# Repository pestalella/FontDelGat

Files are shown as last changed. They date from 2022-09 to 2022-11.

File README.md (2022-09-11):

# FontDelGat
La Font del Gat: a 2 channel power supply. 
Features:
  * 2 output channels, up to 30V and 3A each
  * Possibility to link the 2 channels in series or in parallel
  * User input through buttons and a rotary encoder
  * LCD display to show the voltage and current limits and the actual outputs
  * Possibility to enable or disable the outputs independently

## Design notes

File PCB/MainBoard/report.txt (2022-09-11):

Info: Processing symbol 'U4:footprints:2SC5200NS1_E_S'.
Info: Processing symbol 'U7:Package_QFP:LQFP-64_10x10mm_P0.5mm'.
Info: Processing symbol 'C28:Capacitor_SMD:C_0603_1608Metric_Pad1.08x0.95mm_HandSolder'.
Info: Processing symbol 'C17:Capacitor_SMD:C_0805_2012Metric'.
Info: Processing symbol 'C18:Capacitor_SMD:C_0805_2012Metric'.
Info: Processing symbol 'U5:Package_SO:SOIC-8_3.9x4.9mm_P1.27mm'.
Info: Processing symbol 'C19:Capacitor_THT:CP_Radial_D16.0mm_P7.50mm'.
Info: Processing symbol 'C15:Capacitor_THT:CP_Radial_D8.0mm_P3.80mm'.
Info: Processing symbol 'C21:Capacitor_SMD:C_0603_1608Metric_Pad1.08x0.95mm_HandSolder'.
Info: Processing symbol 'U9:Package_TO_SOT_THT:TO-220-3_Vertical'.
Info: Processing symbol 'C30:Capacitor_SMD:C_0603_1608Metric_Pad1.08x0.95mm_HandSolder'.
Info: Processing symbol 'C23:Capacitor_SMD:C_0603_1608Metric_Pad1.08x0.95mm_HandSolder'.
Info: Processing symbol 'U3:Package_SO:SOIC-14_3.9x8.7mm_P1.27mm'.
Info: Processing symbol 'C24:Capacitor_SMD:C_0603_1608Metric_Pad1.08x0.95mm_HandSolder'.
Info: Processing symbol 'U2:Footprints:ltc2631cts8-hz12-trmpbf'.
Info: Processing symbol 'U1:Footprints:ltc2631cts8-hz12-trmpbf'.
Info: Processing symbol 'C8:Capacitor_SMD:C_1206_3216Metric_Pad1.42x1.75mm_HandSolder'.
Info: Processing symbol 'C1:Capacitor_SMD:C_0603_1608Metric_Pad1.08x0.95mm_HandSolder'.
Info: Processing symbol 'R2:Resistor_SMD:R_0805_2012Metric_Pad1.20x1.40mm_HandSolder'.
Info: Processing symbol 'R3:Resistor_SMD:R_0805_2012Metric_Pad1.20x1.40mm_HandSolder'.
Info: Processing symbol 'R27:Resistor_THT:R_Axial_DIN0207_L6.3mm_D2.5mm_P10.16mm_Horizontal'.
Info: Processing symbol 'Q10:Package_TO_SOT_THT:TO-92_HandSolder'.
Info: Processing symbol 'Q11:Package_TO_SOT_THT:TO-220-3_Vertical'.
Info: Processing symbol 'R34:Resistor_SMD:R_0805_2012Metric_Pad1.20x1.40mm_HandSolder'.
Info: Processing symbol 'Q12:Package_TO_SOT_THT:TO-220-3_Vertical'.
Info: Processing symbol 'R1:Resistor_SMD:R_0805_2012Metric_Pad1.20x1.40mm_HandSolder'.
Info: Processing symbol 'R28:Resistor_SMD:R_0805_2012Metric_Pad1.20x1.40mm_HandSolder'.
Info: Processing symbol 'Y1:Crystal:Crystal_HC49-U_Vertical'.
Info: Processing symbol 'C2:Capacitor_THT:CP_Radial_D8.0mm_P3.80mm'.
Info: Processing symbol 'C3:Capacitor_SMD:C_1206_3216Metric_Pad1.42x1.75mm_HandSolder'.
Info: Processing symbol 'R4:Resistor_SMD:R_0805_2012Metric_Pad1.20x1.40mm_HandSolder'.
Info: Processing symbol 'R26:Resistor_SMD:R_0805_2012Metric_Pad1.20x1.40mm_HandSolder'.
Info: Processing symbol 'R5:Resistor_SMD:R_0805_2012Metric_Pad1.20x1.40mm_HandSolder'.
Info: Processing symbol 'C20:Capacitor_THT:CP_Radial_D16.0mm_P7.50mm'.
Info: Processing symbol 'C16:Capacitor_SMD:C_0603_1608Metric_Pad1.08x0.95mm_HandSolder'.
Info: Processing symbol 'D1:Package_TO_SOT_SMD:SOT-23'.
Info: Processing symbol 'K3:Footprints:Relay_SPDT_Panasonic-ALQ105'.
Info: Processing symbol 'C27:Capacitor_SMD:C_0603_1608Metric_Pad1.08x0.95mm_HandSolder'.
Info: Processing symbol 'D3:Diode_SMD:D_SOD-123'.
Info: Processing symbol 'TP10:TestPoint:TestPoint_THTPad_D2.0mm_Drill1.0mm'.
Info: Processing symbol 'D2:Diode_SMD:D_SOD-123'.
Info: Processing symbol 'TP6:TestPoint:TestPoint_THTPad_D2.0mm_Drill1.0mm'.
Info: Processing symbol 'C26:Capacitor_SMD:C_0603_1608Metric_Pad1.08x0.95mm_HandSolder'.
Info: Processing symbol 'C29:Capacitor_SMD:C_0603_1608Metric_Pad1.08x0.95mm_HandSolder'.
Info: Processing symbol 'D4:Diode_SMD:D_SOD-123'.
Info: Processing symbol 'TP5:TestPoint:TestPoint_THTPad_D2.0mm_Drill1.0mm'.
Info: Processing symbol 'TP9:TestPoint:TestPoint_THTPad_D2.0mm_Drill1.0mm'.
Info: Processing symbol 'C31:Capacitor_SMD:C_1206_3216Metric_Pad1.33x1.80mm_HandSolder'.
Info: Processing symbol 'TP8:TestPoint:TestPoint_THTPad_D2.0mm_Drill1.0mm'.
Info: Processing symbol 'C32:Capacitor_SMD:C_0603_1608Metric_Pad1.08x0.95mm_HandSolder'.
Info: Processing symbol 'TP7:TestPoint:TestPoint_THTPad_D2.0mm_Drill1.0mm'.
Info: Processing symbol 'K1:Footprints:Relay_SPST_Panasonic_ALQ305'.
Info: Processing symbol 'C25:Capacitor_SMD:C_0603_1608Metric_Pad1.08x0.95mm_HandSolder'.
Info: Processing symbol 'C10:Capacitor_THT:CP_Radial_D8.0mm_P3.80mm'.
Info: Processing symbol 'C4:Capacitor_THT:CP_Radial_D8.0mm_P3.80mm'.
Info: Processing symbol 'C5:Capacitor_THT:CP_Radial_D5.0mm_P2.00mm'.
Info: Processing symbol 'C6:Capacitor_SMD:C_0603_1608Metric_Pad1.08x0.95mm_HandSolder'.
Info: Processing symbol 'C7:Capacitor_SMD:C_0603_1608Metric_Pad1.08x0.95mm_HandSolder'.
Info: Processing symbol 'Y2:Crystal:Crystal_C38-LF_D3.0mm_L8.0mm_Horizontal'.
Info: Processing symbol 'TP4:TestPoint:TestPoint_THTPad_D2.0mm_Drill1.0mm'.
Info: Processing symbol 'C9:Capacitor_SMD:C_1206_3216Metric_Pad1.42x1.75mm_HandSolder'.
Info: Processing symbol 'RV1:Footprints:Potentiometer_Panasonic_EVM1D_Vertical'.
Info: Processing symbol 'J3:Connector_Phoenix_MSTB:PhoenixContact_MSTBVA_2,5_3-G-5,08_1x03_P5.08mm_Vertical'.
Info: Processing symbol 'C11:Capacitor_THT:CP_Radial_D8.0mm_P3.80mm'.
Info: Processing symbol 'C12:Capacitor_THT:CP_Radial_D5.0mm_P2.00mm'.
Info: Processing symbol 'U10:Package_TO_SOT_THT:TO-220-3_Vertical'.
Info: Processing symbol 'C13:Capacitor_SMD:C_0603_1608Metric_Pad1.08x0.95mm_HandSolder'.
Info: Processing symbol 'C14:Capacitor_SMD:C_1206_3216Metric_Pad1.42x1.75mm_HandSolder'.
Info: Processing symbol 'U8:Package_TO_SOT_SMD:SOT-223-3_TabPin2'.
Info: Processing symbol 'D6:Package_TO_SOT_SMD:SOT-23'.
Info: Processing symbol 'TP2:TestPoint:TestPoint_THTPad_D2.0mm_Drill1.0mm'.
Info: Processing symbol 'D7:Package_TO_SOT_SMD:SOT-23'.
Info: Processing symbol 'Q1:Package_TO_SOT_THT:TO-220-3_Vertical'.
Info: Processing symbol 'Q2:Package_TO_SOT_SMD:SOT-23'.
Info: Processing symbol 'Q3:Package_TO_SOT_THT:TO-220-3_Vertical'.
Info: Processing symbol 'D11:LED_SMD:LED_0805_2012Metric_Castellated'.
Info: Processing symbol 'D5:Diode_SMD:D_SOD-123'.
Info: Processing symbol 'TP3:TestPoint:TestPoint_THTPad_D2.0mm_Drill1.0mm'.
Info: Processing symbol 'L1:Inductor_SMD:L_0805_2012Metric_Pad1.15x1.40mm_HandSolder'.
Info: Processing symbol 'R17:Resistor_SMD:R_0805_2012Metric_Pad1.20x1.40mm_HandSolder'.
Info: Processing symbol 'M1:Footprints:Fan_Orion_OD7020_vertical'.
Info: Processing symbol 'D8:Package_TO_SOT_SMD:SOT-23'.
Info: Processing symbol 'TP1:TestPoint:TestPoint_THTPad_D2.0mm_Drill1.0mm'.
Info: Processing symbol 'D9:Diode_THT:D_DO-35_SOD27_P10.16mm_Horizontal'.
Info: Processing symbol 'D10:LED_SMD:LED_0805_2012Metric_Castellated'.
Info: Processing symbol 'Q4:Package_TO_SOT_SMD:SOT-23'.
Info: Processing symbol 'R_sense2:Resistor_THT:R_Bare_Metal_Element_L21.3mm_W4.8mm_P20.30mm'.
Info: Processing symbol 'H1:MountingHole:MountingHole_4.3mm_M4_Pad_Via'.
Info: Processing symbol 'Q9:Package_TO_SOT_THT:TO-92_HandSolder'.
Info: Processing symbol 'J4:Connector_Molex:Molex_KK-254_AE-6410-04A_1x04_P2.54mm_Vertical'.
Info: Processing symbol 'R_sense1:Resistor_THT:R_Bare_Metal_Element_L21.3mm_W4.8mm_P20.30mm'.
Info: Processing symbol 'J5:Connector_PinHeader_1.27mm:PinHeader_2x07_P1.27mm_Vertical_SMD'.
Info: Processing symbol 'J6:Connector_Molex:Molex_KK-254_AE-6410-05A_1x05_P2.54mm_Vertical'.
Info: Processing symbol 'J7:Connector_Phoenix_MSTB:PhoenixContact_MSTBVA_2,5_4-G-5,08_1x04_P5.08mm_Vertical'.
Info: Processing symbol 'RV2:Footprints:Potentiometer_Panasonic_EVM1D_Vertical'.
Info: Processing symbol 'R30:Resistor_SMD:R_0805_2012Metric_Pad1.20x1.40mm_HandSolder'.
Info: Processing symbol 'Q8:Package_TO_SOT_SMD:SOT-23'.
Info: Processing symbol 'K2:Footprints:Relay_SPST_Panasonic_ALQ305'.
Info: Processing symbol 'J2:Connector_Phoenix_MSTB:PhoenixContact_MSTBVA_2,5_4-G-5,08_1x04_P5.08mm_Vertical'.
Info: Processing symbol 'K4:Footprints:Relay_SPDT_Panasonic-ALQ105'.
Info: Processing symbol 'R33:Resistor_SMD:R_0805_2012Metric_Pad1.20x1.40mm_HandSolder'.
Info: Processing symbol 'K5:Footprints:Relay_SPDT_Panasonic-ALQ105'.
Info: Processing symbol 'R32:Resistor_SMD:R_0805_2012Metric_Pad1.20x1.40mm_HandSolder'.
Info: Processing symbol 'R16:Resistor_SMD:R_0805_2012Metric_Pad1.20x1.40mm_HandSolder'.
Info: Processing symbol 'H2:MountingHole:MountingHole_4.3mm_M4_Pad_Via'.
Info: Processing symbol 'R12:Resistor_SMD:R_0805_2012Metric_Pad1.20x1.40mm_HandSolder'.
Info: Processing symbol 'R20:Resistor_SMD:R_0805_2012Metric_Pad1.20x1.40mm_HandSolder'.
Info: Processing symbol 'R13:Resistor_SMD:R_0805_2012Metric_Pad1.20x1.40mm_HandSolder'.
Info: Processing symbol 'R19:Resistor_SMD:R_0805_2012Metric_Pad1.20x1.40mm_HandSolder'.
Info: Processing symbol 'R14:Resistor_SMD:R_0805_2012Metric_Pad1.20x1.40mm_HandSolder'.
Info: Processing symbol 'R15:Resistor_SMD:R_0805_2012Metric_Pad1.20x1.40mm_HandSolder'.
Info: Processing symbol 'R18:Resistor_SMD:R_0805_2012Metric_Pad1.20x1.40mm_HandSolder'.
Info: Processing symbol 'R24:Resistor_SMD:R_0805_2012Metric_Pad1.20x1.40mm_HandSolder'.
Info: Processing symbol 'U6:footprints:2SC5200NS1_E_S'.
Info: Processing symbol 'R29:Resistor_SMD:R_0805_2012Metric_Pad1.20x1.40mm_HandSolder'.
Info: Processing symbol 'R31:Resistor_SMD:R_0805_2012Metric_Pad1.20x1.40mm_HandSolder'.
Info: Processing symbol 'Q5:Package_TO_SOT_SMD:SOT-23'.
Info: Processing symbol 'Q6:Package_TO_SOT_SMD:SOT-23'.
Info: Processing symbol 'Q7:Package_TO_SOT_SMD:SOT-23'.
Info: Processing symbol 'D12:Package_TO_SOT_SMD:SOT-23'.
Info: Processing symbol 'R21:Resistor_SMD:R_0805_2012Metric_Pad1.20x1.40mm_HandSolder'.
Info: Processing symbol 'C22:Capacitor_SMD:C_0603_1608Metric_Pad1.08x0.95mm_HandSolder'.
Info: Processing symbol 'R25:Resistor_SMD:R_0805_2012Metric_Pad1.20x1.40mm_HandSolder'.
Info: Processing symbol 'H3:MountingHole:MountingHole_4.3mm_M4_Pad_Via'.
Info: Processing symbol 'H4:MountingHole:MountingHole_4.3mm_M4_Pad_Via'.
Info: Processing symbol 'HS1:Footprints:Heatsink_100x36mm_2xfixations_HorizAirflow'.
Info: Processing symbol 'HS2:Footprints:Heatsink_100x36mm_2xfixations_HorizAirflow'.
Info: Processing symbol 'J1:Connector_JST:JST_EH_B2B-EH-A_1x02_P2.50mm_Vertical'.
Info: Processing symbol 'R11:Resistor_SMD:R_0805_2012Metric_Pad1.20x1.40mm_HandSolder'.
Info: Processing symbol 'R6:Resistor_SMD:R_0805_2012Metric_Pad1.20x1.40mm_HandSolder'.
Info: Processing symbol 'R10:Resistor_SMD:R_0805_2012Metric_Pad1.20x1.40mm_HandSolder'.
Info: Processing symbol 'R7:Resistor_SMD:R_0805_2012Metric_Pad1.20x1.40mm_HandSolder'.
Info: Processing symbol 'R8:Resistor_SMD:R_0805_2012Metric_Pad1.20x1.40mm_HandSolder'.
Info: Processing symbol 'R23:Resistor_SMD:R_0805_2012Metric_Pad1.20x1.40mm_HandSolder'.
Info: Processing symbol 'R22:Resistor_SMD:R_0805_2012Metric_Pad1.20x1.40mm_HandSolder'.
Info: Processing symbol 'R9:Resistor_SMD:R_0805_2012Metric_Pad1.20x1.40mm_HandSolder'.
Reconnect C24 pin 1 from +3V3 to GND.
Reconnect Q1 pin 2 from VccB to VccA.
Update C26 symbol association from /0afd6881-42af-4d43-b93d-c97be1ad281f to /5e31d1d0-74d1-434d-806d-4b33300674fd.
Change C28 value from 12pF to 4.3pF.
Update C28 symbol association from /fe0e0f18-c546-4c73-938a-0cfb9f1ffd65 to /133f106c-29bc-4b4b-84ed-b9e9548e01c3.
Reconnect C28 pin 2 from RCC_OSC_IN to RCC_OSC32_IN.
Change C30 value from 12pF to 4.3pF.
Update C30 symbol association from /9e12a373-cd2f-416b-ab26-eba444fff672 to /b6da05b9-1dae-4554-bf33-a9bfd05ba2d1.
Update R12 symbol association from /00000000-0000-0000-0000-00005f20075e to /00000000-0000-0000-0000-00005f20068b.
Change D1 footprint from 'Diode_THT:D_DO-35_SOD27_P10.16mm_Horizontal' to 'Package_TO_SOT_SMD:SOT-23'.
Change D2 footprint from 'Package_TO_SOT_SMD:SOT-23' to 'Diode_SMD:D_SOD-123'.
Update C25 symbol association from /7236d68b-db3f-4750-9cc2-b887507e6d9c to /0afd6881-42af-4d43-b93d-c97be1ad281f.
Change C1 footprint from 'Capacitor_THT:CP_Radial_D8.0mm_P3.80mm' to 'Capacitor_SMD:C_0603_1608Metric_Pad1.08x0.95mm_HandSolder'.
Update C2 symbol association from /57c7e639-1ec1-4828-a059-563934867bb6 to /f0389591-4e47-43a0-b078-f4fade6f2eda.
Reconnect C2 pin 2 from Net-(C2-Pad2) to V_controlA.
Update C4 symbol association from /0429e6a1-bb74-45cc-b5d5-f3da9a321c81 to /57c7e639-1ec1-4828-a059-563934867bb6.
Reconnect C4 pin 1 from VccB to VccA.
Update R15 symbol association from /00000000-0000-0000-0000-00005f3e354c to /00000000-0000-0000-0000-00005f20065c.
Reconnect R9 pin 2 from VeeB to Net-(D2-Pad1).
Reconnect R9 pin 1 from Net-(C4-Pad2) to VinAP.
Reconnect R10 pin 1 from Net-(D3-Pad1) to Net-(D4-Pad1).
Update R11 symbol association from /00000000-0000-0000-0000-00005f20067d to /00000000-0000-0000-0000-00005f200544.
Reconnect R11 pin 2 from VeeB to VeeA.
Update K5 symbol association from /0c85559d-b62d-4d33-81de-d17b2e255e6b to /9b3b9a1d-c146-4610-bd8e-36d9062b988c.
Reconnect R33 pin 1 from VccBRippled to VccARippled.
Change R12 value from 10k to 150k.
Reconnect C24 pin 2 from GND to Net-(C24-Pad2).
Reconnect R8 pin 1 from Net-(Q4-Pad1) to VinBN.
Change C21 footprint from 'Capacitor_SMD:C_0805_2012Metric' to 'Capacitor_SMD:C_0603_1608Metric_Pad1.08x0.95mm_HandSolder'.
Add C22 (footprint 'Capacitor_SMD:C_0603_1608Metric_Pad1.08x0.95mm_HandSolder').
Add C23 (footprint 'Capacitor_SMD:C_0603_1608Metric_Pad1.08x0.95mm_HandSolder').
Change C24 value from 100nF to 12pF.
Update C24 symbol association from /b5284e8f-654c-4aaf-a072-5e3a8a69abc3 to /9e12a373-cd2f-416b-ab26-eba444fff672.
Update C24 properties.
Add net Net-(C24-Pad2).
Update C16 properties.
Reconnect K2 pin 1 from Net-(D2-Pad1) to Net-(D6-Pad1).
Add K3 (footprint 'Footprints:Relay_SPDT_Panasonic-ALQ105').
Update K4 symbol association from /e12e5867-65d7-4fd2-b077-7e5b1586e36a to /0c85559d-b62d-4d33-81de-d17b2e255e6b.
Reconnect K4 pin 5 from VinAN to VinAP.
Reconnect K4 pin 4 from Net-(K4-Pad4) to VoutBP.
Reconnect K4 pin 3 from VinBN to VinBP.
Update D3 symbol association from /00000000-0000-0000-0000-00005f2006a1 to /00000000-0000-0000-0000-00005f20069b.
Reconnect K5 pin 4 from VoutBP to VoutBN.
Change C5 footprint from 'Capacitor_THT:CP_Radial_D8.0mm_P3.80mm' to 'Capacitor_THT:CP_Radial_D5.0mm_P2.00mm'.
Reconnect K5 pin 3 from VinBP to Net-(K3-Pad4).
Add net Net-(D12-Pad1).
Reconnect K5 pin 1 from Net-(D9-Pad1) to Net-(D12-Pad1).
Update Q1 symbol association from /00000000-0000-0000-0000-00005f20064a to /00000000-0000-0000-0000-00005f200515.
Reconnect R16 pin 1 from Net-(D6-Pad1) to Net-(R16-Pad1).
Reconnect Q1 pin 1 from V_controlB to V_controlA.
Change Q2 footprint from 'Package_TO_SOT_THT:TO-220-3_Vertical' to 'Package_TO_SOT_SMD:SOT-23'.
Remove unused footprint K6.
Add net Net-(K3-Pad4).
Change C6 footprint from 'Capacitor_THT:CP_Radial_D16.0mm_P7.50mm' to 'Capacitor_SMD:C_0603_1608Metric_Pad1.08x0.95mm_HandSolder'.
Change C7 footprint from 'Capacitor_THT:CP_Radial_D16.0mm_P7.50mm' to 'Capacitor_SMD:C_0603_1608Metric_Pad1.08x0.95mm_HandSolder'.
Change C10 footprint from 'Capacitor_SMD:C_0805_2012Metric' to 'Capacitor_THT:CP_Radial_D8.0mm_P3.80mm'.
Change C20 footprint from 'Capacitor_THT:CP_Radial_D5.0mm_P2.00mm' to 'Capacitor_THT:CP_Radial_D16.0mm_P7.50mm'.
Change C12 footprint from 'Capacitor_SMD:C_1206_3216Metric_Pad1.42x1.75mm_HandSolder' to 'Capacitor_THT:CP_Radial_D5.0mm_P2.00mm'.
Change C15 footprint from 'Capacitor_THT:CP_Radial_D5.0mm_P2.00mm' to 'Capacitor_THT:CP_Radial_D8.0mm_P3.80mm'.
Change C16 value from 100nF to 4.7uF.
Update C16 symbol association from /00000000-0000-0000-0000-00005f16083f to /28637788-f991-4e02-bbe8-3ca3781fa436.
Reconnect C30 pin 2 from Net-(C30-Pad2) to RCC_OSC32_OUT.
Add net Net-(C16-Pad1).
Reconnect C16 pin 1 from +5V to Net-(C16-Pad1).
Change C17 footprint from 'Capacitor_SMD:C_1206_3216Metric_Pad1.42x1.75mm_HandSolder' to 'Capacitor_SMD:C_0805_2012Metric'.
Change C18 footprint from 'Capacitor_SMD:C_0603_1608Metric_Pad1.08x0.95mm_HandSolder' to 'Capacitor_SMD:C_0805_2012Metric'.
Change C19 footprint from 'Capacitor_SMD:C_1206_3216Metric_Pad1.42x1.75mm_HandSolder' to 'Capacitor_THT:CP_Radial_D16.0mm_P7.50mm'.
Change C11 footprint from 'Capacitor_SMD:C_0603_1608Metric_Pad1.08x0.95mm_HandSolder' to 'Capacitor_THT:CP_Radial_D8.0mm_P3.80mm'.
Change K2 value from OUT_A_ENABLE_RELAY to OUT_B_ENABLE_RELAY.
Update K2 symbol association from /00000000-0000-0000-0000-00005f200627 to /00000000-0000-0000-0000-00005f2006ca.
Reconnect Q10 pin 3 from VccBRippled to VccARippled.
Reconnect Q5 pin 3 from Net-(D8-Pad1) to Net-(D7-Pad1).
Reconnect Q6 pin 3 from Net-(D9-Pad1) to Net-(D8-Pad1).
Update Q7 symbol association from /94f5b71e-5ff4-4d31-9d77-152d3f2b07b1 to /e29cb0bd-31bd-41a6-99d9-c935a9c73646.
Add net Net-(J1-Pad1).
Reconnect Q7 pin 3 from Net-(D10-Pad1) to Net-(J1-Pad1).
Add Q8 (footprint 'Package_TO_SOT_SMD:SOT-23').
Change R2 footprint from 'Resistor_THT:R_Axial_DIN0207_L6.3mm_D2.5mm_P10.16mm_Horizontal' to 'Resistor_SMD:R_0805_2012Metric_Pad1.20x1.40mm_HandSolder'.
Reconnect R6 pin 2 from V_controlA to VeeA.
Change Q9 footprint from 'Package_TO_SOT_SMD:SOT-23' to 'Package_TO_SOT_THT:TO-92_HandSolder'.
Add net Net-(C20-Pad1).
Reconnect Q10 pin 2 from Net-(C6-Pad1) to Net-(C20-Pad1).
Change Q11 footprint from 'Package_TO_SOT_THT:TO-92_HandSolder' to 'Package_TO_SOT_THT:TO-220-3_Vertical'.
Add net Net-(Q12-Pad1).
Reconnect Q12 pin 1 from Net-(Q10-Pad1) to Net-(Q12-Pad1).
Change R1 value from 47 to 300k.
Change R5 value from 220k to 10k.
Update R1 properties.
Update R5 symbol association from /00000000-0000-0000-0000-00005f20065c to /00000000-0000-0000-0000-00005f200743.
Reconnect R1 pin 1 from RCC_OSC_OUT to VccA.
Reconnect R3 pin 1 from Net-(Q3-Pad1) to Net-(Q2-Pad1).
Change R4 value from 300k to 20k.
Update R4 symbol association from /00000000-0000-0000-0000-00005f200662 to /00000000-0000-0000-0000-00005f200521.
Update R4 properties.
Reconnect R4 pin 2 from V_controlB to VeeA.
Reconnect R4 pin 1 from VccB to Net-(C4-Pad2).
Update R1 symbol association from /d5d2f71c-7837-4aa9-9223-268e15ef8f1c to /00000000-0000-0000-0000-00005f20052d.
Reconnect R6 pin 1 from VccA to Net-(D2-Pad1).
Update R5 properties.
Reconnect R5 pin 2 from VeeB to Net-(Q2-Pad1).
Reconnect R5 pin 1 from V_controlB to GND.
Change R6 value from 300k to 10k.
Update R6 symbol association from /00000000-0000-0000-0000-00005f20052d to /00000000-0000-0000-0000-00005f3e354c.
Update R6 properties.
Update R7 properties.
Add net Net-(Q2-Pad1).
Reconnect R7 pin 2 from VeeA to VeeB.
Reconnect R15 pin 1 from Net-(D4-Pad1) to V_controlB.
Update R16 symbol association from /00000000-0000-0000-0000-00005f200544 to /00000000-0000-0000-0000-00005f1ef45a.
Reconnect R16 pin 2 from VeeA to GND.
Add net Net-(R16-Pad1).
Update R14 properties.
Change R7 value from 220k to 10k.
Change Q3 footprint from 'Package_TO_SOT_SMD:SOT-23' to 'Package_TO_SOT_THT:TO-220-3_Vertical'.
Reconnect R13 pin 2 from VeeA to Net-(D5-Pad1).
Reconnect R15 pin 2 from VeeA to VeeB.
Reconnect R7 pin 1 from V_controlA to Net-(D3-Pad1).
Change R8 value from 1k to 150k.
Update R8 symbol association from /00000000-0000-0000-0000-00005f2006b8 to /00000000-0000-0000-0000-00005f200677.
Update R8 properties.
Reconnect R8 pin 2 from OUTB_EN to Net-(D3-Pad1).
Update R12 properties.
Change R9 value from 20k to 150k.
Update R15 properties.
Reconnect R13 pin 1 from Net-(C2-Pad2) to VinAN.
Reconnect R1 pin 2 from Net-(C30-Pad2) to V_controlA.
Update Q10 symbol association from /533e4858-8b01-4de2-a8bf-871163b96f09 to /0a8306ce-390e-424e-8d39-42ea2c37b6c3.
Reconnect R12 pin 2 from Net-(Q4-Pad1) to Net-(D4-Pad1).
Reconnect R12 pin 1 from GND to VinBP.
Change R13 value from 20k to 150k.
Update R13 symbol association from /00000000-0000-0000-0000-00005f200521 to /00000000-0000-0000-0000-00005f20053e.
Update R13 properties.
Reconnect Q4 pin 3 from Net-(D7-Pad1) to Net-(D6-Pad1).
Update R9 properties.
Change R14 value from 10k to 300k.
Update R14 symbol association from /00000000-0000-0000-0000-00005f200743 to /00000000-0000-0000-0000-00005f200662.
Update R7 symbol association from /00000000-0000-0000-0000-00005f200527 to /00000000-0000-0000-0000-00005f20067d.
Reconnect R14 pin 2 from Net-(Q3-Pad1) to V_controlB.
Reconnect R14 pin 1 from GND to VccB.
Change R15 value from 10k to 220k.
Reconnect via from Net-(C7-Pad1) to Net-(C24-Pad2).
Update R9 symbol association from /00000000-0000-0000-0000-00005f200656 to /00000000-0000-0000-0000-00005f3b43e1.
Update R32 properties.
Reconnect Q7 pin 1 from Net-(Q7-Pad1) to FAN_CTRL.
Change R20 value from 150k to 10k.
Update R21 properties.
Update R20 properties.
Remove unused footprint D13.
Reconnect R20 pin 2 from Net-(D4-Pad1) to GND.
Add net Net-(R20-Pad1).
Reconnect R20 pin 1 from VinAP to Net-(R20-Pad1).
Reconnect R17 pin 1 from VinBN to Net-(Q4-Pad1).
Change R21 value from 4.7k to 1k.
Update R21 symbol association from /7e725a62-139d-453e-b5e5-5569dbe8de09 to /fabcb578-24bb-4d0b-b0cf-7d8736598d5f.
Update R20 symbol association from /00000000-0000-0000-0000-00005f3b43e1 to /00000000-0000-0000-0000-00005f1f2a6d.
Reconnect TP10 pin 1 from +12V to +3V3.
Change R17 value from 150k to 1k.
Update R17 symbol association from /00000000-0000-0000-0000-00005f200677 to /00000000-0000-0000-0000-00005f2006b8.
Update R17 properties.
Reconnect R17 pin 2 from Net-(D5-Pad1) to OUTB_EN.
Reconnect U10 pin 3 from V_TEMP_A to V_TEMP_B.
Add net Net-(C19-Pad1).
Reconnect R31 pin 2 from GND to Net-(C19-Pad1).
Update U4 symbol association from /00000000-0000-0000-0000-00005f200774 to /00000000-0000-0000-0000-00005f20076a.
Update R33 symbol association from /4239c2c7-a453-4457-b6be-9e3e8799ad40 to /037e429e-1ced-441d-b81b-0a1fc8cbe772.
Reconnect R31 pin 1 from Net-(R31-Pad1) to VccBRippled.
Change TP10 value from TP_12V to TP_3V3.
Change R32 value from 10k to 4.7k.
Update R32 symbol association from /00000000-0000-0000-0000-00005f1f2a6d to /760a1871-5ef4-46f2-8d8c-3169e411039a.
Reconnect R19 pin 1 from VinAN to GND.
Reconnect R32 pin 2 from GND to I2C1_SDA.
Change U3 footprint from 'Package_TO_SOT_SMD:SOT-23-6_Handsoldering' to 'Package_SO:SOIC-14_3.9x8.7mm_P1.27mm'.
Reconnect R32 pin 1 from Net-(R32-Pad1) to +3V3.
Update R_sense1 symbol association from /00000000-0000-0000-0000-00005f200650 to /00000000-0000-0000-0000-00005f20051b.
Update R19 symbol association from /00000000-0000-0000-0000-00005f20053e to /00000000-0000-0000-0000-00005f20075e.
Update R19 properties.
Reconnect R19 pin 2 from Net-(D6-Pad1) to Net-(Q4-Pad1).
Reconnect TP4 pin 1 from Net-(D3-Pad1) to Net-(D4-Pad1).
Reconnect R24 pin 1 from +3V3 to GND.
Reconnect R23 pin 1 from Net-(Q6-Pad1) to GND.
Reconnect R23 pin 2 from PARALLEL_OUT to Net-(Q5-Pad1).
Update R23 properties.
Reconnect R24 pin 2 from I2C1_SDA to Net-(Q6-Pad1).
Change R23 value from 1k to 10k.
Reconnect TP3 pin 1 from Net-(D6-Pad1) to Net-(D5-Pad1).
Reconnect R21 pin 2 from +3V3 to PARALLEL_OUT.
Reconnect via from Net-(C6-Pad1) to Net-(C20-Pad1).
Reconnect D4 pin 2 from VeeA to VeeB.
Update R25 properties.
Update R23 symbol association from /ab851e10-6952-453a-94c1-2661101c520a to /4335abfb-00af-4766-93d5-d969c1b34ab0.
Reconnect TP1 pin 1 from Net-(D5-Pad1) to Net-(D3-Pad1).
Update R22 symbol association from /fabcb578-24bb-4d0b-b0cf-7d8736598d5f to /ab851e10-6952-453a-94c1-2661101c520a.
Update R25 symbol association from /4335abfb-00af-4766-93d5-d969c1b34ab0 to /fbed71fa-055c-4ad1-8676-ac6ffce9f56b.
Reconnect R22 pin 1 from Net-(Q5-Pad1) to Net-(Q6-Pad1).
Change R25 value from 10k to 1k.
Reconnect R21 pin 1 from I2C1_SCL to Net-(Q5-Pad1).
Reconnect TP2 pin 1 from Net-(D4-Pad1) to Net-(D2-Pad1).
Remove unused footprint Q13.
Change R19 value from 150k to 10k.
Remove unused footprint C33.
Update R18 symbol association from /00000000-0000-0000-0000-00005f20068b to /00000000-0000-0000-0000-00005f200656.
Update R18 properties.
Reconnect R18 pin 2 from Net-(D3-Pad1) to VeeB.
Add net Net-(C11-Pad2).
Reconnect R18 pin 1 from VinBP to Net-(C11-Pad2).
Reconnect K1 pin 1 from Net-(D7-Pad1) to Net-(D1-Pad1).
Remove unused footprint C34.
Remove unused footprint D14.
Change R18 value from 150k to 20k.
Update R24 properties.
Update R24 symbol association from /760a1871-5ef4-46f2-8d8c-3169e411039a to /cb525f28-8e7f-4ee2-9805-5ae0101fe70b.
Reconnect R_sense2 pin 1 from VinAN to VinBN.
Change R24 value from 4.7k to 10k.
Reconnect Y1 pin 1 from Net-(C30-Pad2) to Net-(C24-Pad2).
Update R29 properties.
Change R30 value from 1k to 4.7k.
Add net Net-(D1-Pad1).
Change J1 footprint from 'Connector_Phoenix_MSTB:PhoenixContact_MSTBVA_2,5_4-G-5,08_1x04_P5.08mm_Vertical' to 'Connector_JST:JST_EH_B2B-EH-A_1x02_P2.50mm_Vertical'.
Reconnect R_sense1 pin 1 from VinBN to VinAN.
Reconnect R30 pin 1 from Net-(D14-Pad2) to I2C1_SCL.
Change U5 footprint from 'footprints:2SC5200NS1_E_S' to 'Package_SO:SOIC-8_3.9x4.9mm_P1.27mm'.
Reconnect R30 pin 2 from +12V to +3V3.
Update R30 properties.
Add D12 (footprint 'Package_TO_SOT_SMD:SOT-23').
Reconnect K1 pin 3 from VinBP to VinAP.
Reconnect TP9 pin 1 from +3V3 to +12V.
Update TP9 symbol association from /a5871945-16f7-4283-bb1c-37303574df76 to /cd934ef3-b7d9-4328-9e3d-24b66816d6a6.
Reconnect R29 pin 1 from Net-(D13-Pad2) to Net-(D11-Pad2).
Change U7 footprint from 'Package_TO_SOT_SMD:SOT-23-6_Handsoldering' to 'Package_QFP:LQFP-64_10x10mm_P0.5mm'.
Add net Net-(D11-Pad2).
Change TP9 value from TP_3V3 to TP_12V.
Reconnect R29 pin 2 from +5V to +12V.
Reconnect R25 pin 2 from Net-(Q5-Pad1) to SERIES_OUT.
Reconnect K2 pin 3 from VinAP to VinBP.
Update D4 symbol association from /00000000-0000-0000-0000-00005f200568 to /00000000-0000-0000-0000-00005f2006a1.
Update D5 symbol association from /00000000-0000-0000-0000-00005f20069b to /00000000-0000-0000-0000-00005f200562.
Reconnect D5 pin 2 from VeeB to VeeA.
Change D6 footprint from 'Diode_SMD:D_SOD-123' to 'Package_TO_SOT_SMD:SOT-23'.
Update D7 symbol association from /2c2ce75a-faed-4e0d-a7c3-92d5e09caaea to /418fd569-4b4e-44c2-88d9-3c30dc9974c4.
Update D8 symbol association from /418fd569-4b4e-44c2-88d9-3c30dc9974c4 to /f3bb2890-481f-41ba-8f85-9a3840c670ce.
Change D9 footprint from 'Package_TO_SOT_SMD:SOT-23' to 'Diode_THT:D_DO-35_SOD27_P10.16mm_Horizontal'.
Reconnect U4 pin 2 from VccB to VccA.
Update R31 symbol association from /00000000-0000-0000-0000-00005f1ef45a to /4239c2c7-a453-4457-b6be-9e3e8799ad40.
Change J2 footprint from 'Connector_Phoenix_MSTB:PhoenixContact_MSTBVA_2,5_3-G-5,08_1x03_P5.08mm_Vertical' to 'Connector_Phoenix_MSTB:PhoenixContact_MSTBVA_2,5_4-G-5,08_1x04_P5.08mm_Vertical'.
Change J3 footprint from 'Connector_Phoenix_MSTB:PhoenixContact_MSTBVA_2,5_4-G-5,08_1x04_P5.08mm_Vertical' to 'Connector_Phoenix_MSTB:PhoenixContact_MSTBVA_2,5_3-G-5,08_1x03_P5.08mm_Vertical'.
Change J4 footprint from 'Connector_PinHeader_1.27mm:PinHeader_2x07_P1.27mm_Vertical_SMD' to 'Connector_Molex:Molex_KK-254_AE-6410-04A_1x04_P2.54mm_Vertical'.
Change J5 footprint from 'Connector_Molex:Molex_KK-254_AE-6410-04A_1x04_P2.54mm_Vertical' to 'Connector_PinHeader_1.27mm:PinHeader_2x07_P1.27mm_Vertical_SMD'.
Change J6 footprint from 'Connector_JST:JST_EH_B2B-EH-A_1x02_P2.50mm_Vertical' to 'Connector_Molex:Molex_KK-254_AE-6410-05A_1x05_P2.54mm_Vertical'.
Change J7 footprint from 'Connector_Molex:Molex_KK-254_AE-6410-05A_1x05_P2.54mm_Vertical' to 'Connector_Phoenix_MSTB:PhoenixContact_MSTBVA_2,5_4-G-5,08_1x04_P5.08mm_Vertical'.
Change K1 value from OUT_B_ENABLE_RELAY to OUT_A_ENABLE_RELAY.
Update R34 properties.
Change R28 value from 10k to 220.
Change R34 value from 1k to 47.
Reconnect RV1 pin 2 from Net-(R31-Pad1) to Net-(R16-Pad1).
Reconnect RV1 pin 3 from Net-(R31-Pad1) to Net-(R16-Pad1).
Reconnect RV2 pin 2 from Net-(R32-Pad1) to Net-(R20-Pad1).
Reconnect R34 pin 1 from VccARippled to RCC_OSC_OUT.
Reconnect R34 pin 2 from Net-(C7-Pad1) to Net-(C24-Pad2).
Change U2 footprint from 'Package_SO:SOIC-14_3.9x8.7mm_P1.27mm' to 'Footprints:ltc2631cts8-hz12-trmpbf'.
Update R29 symbol association from /00000000-0000-0000-0000-00005f1d9035 to /00000000-0000-0000-0000-00005f1d7f47.
Update R31 properties.
Change R29 value from 220 to 1k.
Update TP10 symbol association from /cd934ef3-b7d9-4328-9e3d-24b66816d6a6 to /a5871945-16f7-4283-bb1c-37303574df76.
Reconnect RV2 pin 1 from Net-(R32-Pad1) to Net-(R20-Pad1).
Reconnect R33 pin 2 from Net-(C6-Pad1) to Net-(C20-Pad1).
Reconnect R_sense1 pin 2 from VeeB to VeeA.
Change R31 value from 10k to 1k.
Update R34 symbol association from /037e429e-1ced-441d-b81b-0a1fc8cbe772 to /d5d2f71c-7837-4aa9-9223-268e15ef8f1c.
Reconnect R25 pin 1 from GND to Net-(Q8-Pad1).
Update R30 symbol association from /00000000-0000-0000-0000-00005f1d7f47 to /7e725a62-139d-453e-b5e5-5569dbe8de09.
Add net Net-(Q8-Pad1).
Change U9 footprint from 'Package_QFP:LQFP-64_10x10mm_P0.5mm' to 'Package_TO_SOT_THT:TO-220-3_Vertical'.
Reconnect R28 pin 1 from GND to Net-(D10-Pad2).
Add net Net-(D10-Pad2).
Reconnect R28 pin 2 from Net-(Q7-Pad1) to +5V.
Update R28 properties.
Update R28 symbol association from /a923bb61-58c2-4811-9863-8b0e16892b59 to /00000000-0000-0000-0000-00005f1d9035.
Update K1 symbol association from /00000000-0000-0000-0000-00005f2006ca to /00000000-0000-0000-0000-00005f200627.
Change R27 footprint from 'Resistor_SMD:R_0805_2012Metric_Pad1.20x1.40mm_HandSolder' to 'Resistor_THT:R_Axial_DIN0207_L6.3mm_D2.5mm_P10.16mm_Horizontal'.
Update R_sense2 symbol association from /00000000-0000-0000-0000-00005f20051b to /00000000-0000-0000-0000-00005f200650.
Reconnect R26 pin 2 from Net-(Q6-Pad1) to Net-(Q8-Pad1).
Update U10 symbol association from /5a5ea0e8-5904-47fa-8361-9367c56b921a to /00000000-0000-0000-0000-00005f0fe3cc.
Update R26 symbol association from /cb525f28-8e7f-4ee2-9805-5ae0101fe70b to /a923bb61-58c2-4811-9863-8b0e16892b59.
Reconnect R_sense2 pin 2 from VeeA to VeeB.
Change U1 footprint from 'Package_TO_SOT_THT:TO-220-3_Vertical' to 'Footprints:ltc2631cts8-hz12-trmpbf'.
Error: Cannot add D11 (footprint 'LED_SMD:LED_0805_2012Metric_Castellated' not found).
Error: Cannot update C9 (footprint 'Capacitor_SMD:C_1206_3216Metric_Pad1.42x1.75mm_HandSolder' not found).
Error: Cannot update C8 (footprint 'Capacitor_SMD:C_1206_3216Metric_Pad1.42x1.75mm_HandSolder' not found).
Error: Cannot update D10 (footprint 'LED_SMD:LED_0805_2012Metric_Castellated' not found).
Error: Cannot update U6 (footprint 'footprints:2SC5200NS1_E_S' not found).
Error: Cannot update C3 (footprint 'Capacitor_SMD:C_1206_3216Metric_Pad1.42x1.75mm_HandSolder' not found).

Info: Total warnings: 0, errors: 6.

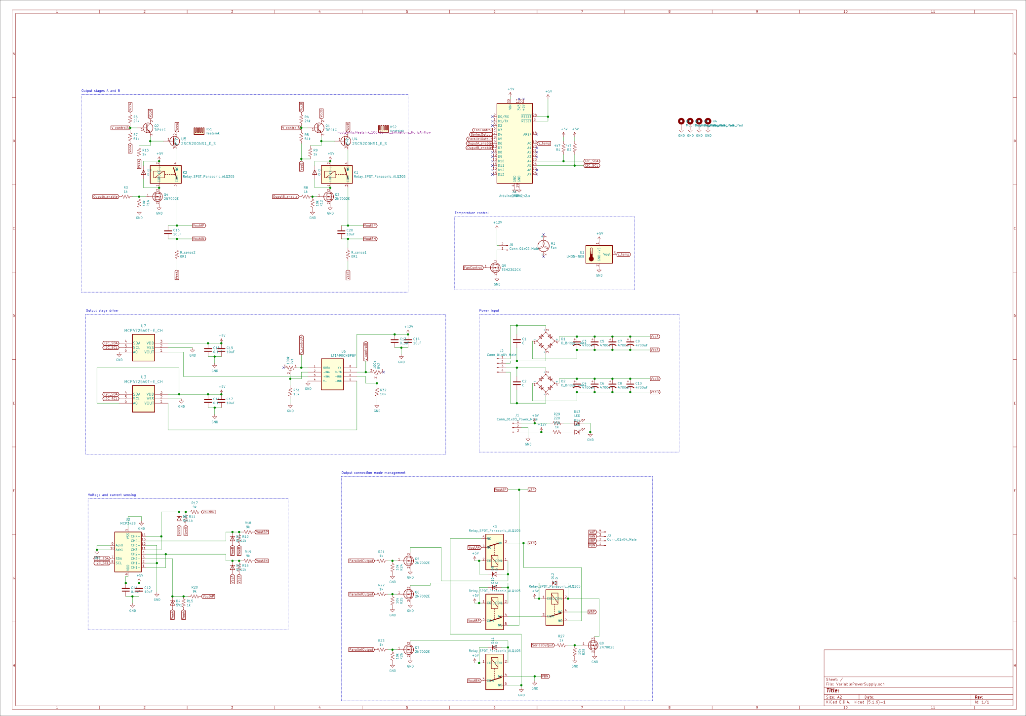
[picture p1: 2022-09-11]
PCB/MainBoard/MainBoard.png

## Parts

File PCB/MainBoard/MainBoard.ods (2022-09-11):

Source: | /home/pau/repos/VariablePowerSupply/PCB/VariablePowerSupply.kicad_sch
Date: | Thu 28 Apr 2022 20:23:53 CEST
Tool: | Eeschema 6.0.3-a3aad9c10e~116~ubuntu20.04.1
Generator: | /usr/share/kicad/plugins/bom_csv_grouped_by_value_with_fp.py
Component Count: | 134
Ref | Qnty | Value | Cmp name | Footprint | Description | Vendor
C1, C2, C3, C4, C5, | 5 | 100uF | C | Capacitor_THT:CP_Radial_D8.0mm_P3.80mm | Unpolarized capacitor
C6, C7, | 2 | 1000uF | C | Capacitor_THT:CP_Radial_D16.0mm_P7.50mm | Unpolarized capacitor
C8, | 1 | 4.7uF (low ESR <1ohm) | C_Small | Capacitor_SMD:C_0603_1608Metric_Pad1.08x0.95mm_HandSolder | Unpolarized capacitor, small symbol
C9, C24, C25, C26, C27, C32, | 6 | 100n | C_Small | Capacitor_SMD:C_0603_1608Metric_Pad1.08x0.95mm_HandSolder | Unpolarized capacitor, small symbol
C11, C13, C16, C18, | 4 | 0.1uF | C | Capacitor_SMD:C_0603_1608Metric_Pad1.08x0.95mm_HandSolder | Unpolarized capacitor
C12, C14, C15, C17, C19, C20, | 6 | 10uF | C | Capacitor_SMD:C_1206_3216Metric_Pad1.42x1.75mm_HandSolder | Unpolarized capacitor
C28, C30, | 2 | 12p | C_Small | Capacitor_SMD:C_0603_1608Metric_Pad1.08x0.95mm_HandSolder | Unpolarized capacitor, small symbol
C29, | 1 | 4u7 | C_Small | Capacitor_SMD:C_0603_1608Metric_Pad1.08x0.95mm_HandSolder | Unpolarized capacitor, small symbol
C31, | 1 | 1u | C_Small | Capacitor_SMD:C_1206_3216Metric_Pad1.33x1.80mm_HandSolder | Unpolarized capacitor, small symbol
C33, C34, | 2 | 4p3 | C_Small | Capacitor_SMD:C_0603_1608Metric_Pad1.08x0.95mm_HandSolder | Unpolarized capacitor, small symbol
D1, | 1 | Zener 33V | D_Zener | Diode_THT:D_DO-35_SOD27_P10.16mm_Horizontal | Zener diode
D2, D7, D8, D9, D10, | 5 | BAS20 | BAS20 | Package_TO_SOT_SMD:SOT-23 | 200V, 0.4A, High-speed Switching Diode, SOT-23
D3, D4, D5, D6, | 4 | 5V1 | D_Zener | Diode_SMD:D_SOD-123 | Zener diode
D13, D14, | 2 | LED | LED | LED_SMD:LED_0805_2012Metric_Castellated | Light emitting diode
H1, H2, H3, H4, | 4 | MountingHole_Pad | MountingHole_Pad | MountingHole:MountingHole_4.3mm_M4_Pad_Via | Mounting Hole with connection
HS1, HS2, | 2 | Heatsink | Heatsink | Footprints:Heatsink_100x36mm_2xfixations_HorizAirflow | Heatsink
J1, | 1 | PowerIn | Conn_PowerOut_01x04_Male | Connector_Molex:Molex_KK-396_A-41791-0004_1x04_P3.96mm_Vertical | Generic connector, single row, 01x04, script generated (kicad-library-utils/schlib/autogen/connector/)
J2, | 1 | AuxPowerIn | Conn_PowerOut_01x03_Male | Connector_Molex:Molex_KK-396_A-41791-0003_1x03_P3.96mm_Vertical | Generic connector, single row, 01x04, script generated (kicad-library-utils/schlib/autogen/connector/)
J3, | 1 | PowerOut | Conn_01x04_Male | Connector_Molex:Molex_KK-396_A-41791-0004_1x04_P3.96mm_Vertical | Generic connector, single row, 01x04, script generated (kicad-library-utils/schlib/autogen/connector/)
J4, | 1 | SWD | Conn_02x07_Odd_Even | Connector_PinHeader_1.27mm:PinHeader_2x07_P1.27mm_Vertical_SMD | Generic connector, double row, 02x07, odd/even pin numbering scheme (row 1 odd numbers, row 2 even numbers), script generated (kicad-library-utils/schlib/autogen/connector/)
J5, | 1 | LCD Display | Conn_01x04 | Connector_Molex:Molex_KK-254_AE-6410-04A_1x04_P2.54mm_Vertical | Generic connector, single row, 01x04, script generated (kicad-library-utils/schlib/autogen/connector/)
J6, | 1 | Fan | Conn_01x02_Male | Connector_JST:JST_EH_B2B-EH-A_1x02_P2.50mm_Vertical | Generic connector, single row, 01x02, script generated (kicad-library-utils/schlib/autogen/connector/)
J7, | 1 | FrontPanel | Conn_01x05 | Connector_Molex:Molex_KK-254_AE-6410-05A_1x05_P2.54mm_Vertical | Generic connector, single row, 01x05, script generated (kicad-library-utils/schlib/autogen/connector/)
K1, | 1 | OUT_B_ENABLE_RELAY | Relay_SPST_Panasonic_ALQ305 | Footprints:Relay_SPST_Panasonic_ALQ305 | Standex Meder DIP reed relay, SPST, Closing Contact
K2, | 1 | OUT_A_ENABLE_RELAY | Relay_SPST_Panasonic_ALQ305 | Footprints:Relay_SPST_Panasonic_ALQ305 | Standex Meder DIP reed relay, SPST, Closing Contact
K4, K5, K6, | 3 | Relay_SPDT_Panasonic_ALQ105 | Relay_SPDT_Panasonic_ALQ105 | Footprints:Relay_SPDT_Panasonic-ALQ105 | Standex Meder DIP reed relay, SPDT
L1, | 1 | 39n | L | Inductor_SMD:L_0805_2012Metric_Pad1.15x1.40mm_HandSolder | Inductor
M1, | 1 | Fan | Fan | Footprints:Fan_Orion_OD7020_vertical | Fan
Q1, Q2, Q12, Q13, | 4 | TIP41C | TIP41C | Package_TO_SOT_THT:TO-220-3_Vertical | 6A Ic, 100V Vce, Power NPN Transistor, TO-220
Q3, Q4, Q5, Q6, Q7, | 5 | 2N7002 | 2N7002 | Package_TO_SOT_SMD:SOT-23 | 0.115A Id, 60V Vds, N-Channel MOSFET, SOT-23
Q9, | 1 | TSM2302CX | Transistor_FET:TSM2302CX_1 | Package_TO_SOT_SMD:SOT-23 | 3.9A Id, 20V Vds, N-Channel MOSFET, SOT-23
Q10, Q11, | 2 | 2N2222 | Q_NPN_EBC | Package_TO_SOT_THT:TO-92_HandSolder | NPN transistor, emitter/base/collector
R1, | 1 | 47 | R_US | Resistor_SMD:R_0805_2012Metric_Pad1.20x1.40mm_HandSolder | Resistor, US symbol
R2, | 1 | 5k | R_US | Resistor_THT:R_Axial_DIN0207_L6.3mm_D2.5mm_P10.16mm_Horizontal | Resistor, US symbol
R3, R8, R22, R23, R27, R30, R33, R34, | 8 | 1k | R_US | Resistor_SMD:R_0805_2012Metric_Pad1.20x1.40mm_HandSolder | Resistor, US symbol
R4, R6, | 2 | 300k | R_US | Resistor_SMD:R_0805_2012Metric_Pad1.20x1.40mm_HandSolder | Resistor, US symbol
R5, R7, | 2 | 220k | R_US | Resistor_SMD:R_0805_2012Metric_Pad1.20x1.40mm_HandSolder | Resistor, US symbol
R9, R13, | 2 | 20k | R_US | Resistor_SMD:R_0805_2012Metric_Pad1.20x1.40mm_HandSolder | Resistor, US symbol
R10, R11, R12, R14, R15, R16, R25, R28, R31, R32, | 10 | 10k | R_US | Resistor_SMD:R_0805_2012Metric_Pad1.20x1.40mm_HandSolder | Resistor, US symbol
R17, R18, R19, R20, | 4 | 150k | R_US | Resistor_SMD:R_0805_2012Metric_Pad1.20x1.40mm_HandSolder | Resistor, US symbol
R21, R24, | 2 | 4.7k | R_US | Resistor_SMD:R_0805_2012Metric_Pad1.20x1.40mm_HandSolder | Resistor, US symbol
R26, | 1 | 10K | R_US | Resistor_SMD:R_0805_2012Metric_Pad1.20x1.40mm_HandSolder | Resistor, US symbol
R29, | 1 | 220 | R_US | Resistor_SMD:R_0805_2012Metric_Pad1.20x1.40mm_HandSolder | Resistor, US symbol
R_sense1, R_sense2, | 2 | 0R1 | R_US | Resistor_THT:R_Bare_Metal_Element_L21.3mm_W4.8mm_P20.30mm | Resistor, US symbol
RV1, RV2, | 2 | 100k | R_POT_TRIM_US-Device | Footprints:Potentiometer_Panasonic_EVM1D_Vertical
TP1, | 1 | TP_BN | TestPoint | TestPoint:TestPoint_THTPad_D2.0mm_Drill1.0mm | test point
TP2, | 1 | TP_AP | TestPoint | TestPoint:TestPoint_THTPad_D2.0mm_Drill1.0mm | test point
TP3, | 1 | TP_AN | TestPoint | TestPoint:TestPoint_THTPad_D2.0mm_Drill1.0mm | test point
TP4, | 1 | TP_BP | TestPoint | TestPoint:TestPoint_THTPad_D2.0mm_Drill1.0mm | test point
TP5, | 1 | TP_CTRL_A | TestPoint | TestPoint:TestPoint_THTPad_D2.0mm_Drill1.0mm | test point
TP6, | 1 | TP_CTRL_B | TestPoint | TestPoint:TestPoint_THTPad_D2.0mm_Drill1.0mm | test point
TP7, | 1 | TP_33V | TestPoint | TestPoint:TestPoint_THTPad_D2.0mm_Drill1.0mm | test point
TP8, | 1 | TP_5V | TestPoint | TestPoint:TestPoint_THTPad_D2.0mm_Drill1.0mm | test point
TP9, | 1 | TP_3V3 | TestPoint | TestPoint:TestPoint_THTPad_D2.0mm_Drill1.0mm | test point
TP10, | 1 | TP_12V | TestPoint | TestPoint:TestPoint_THTPad_D2.0mm_Drill1.0mm | test point
U1, U10, | 2 | LM35-NEB | LM35-NEB | Package_TO_SOT_THT:TO-220-3_Vertical | Precision centigrade temperature sensor, TO-220
U2, | 1 | MCP3428 | MCP3428 | Package_SO:SOIC-14_3.9x8.7mm_P1.27mm | 16-Bit, Multi-Channel ΔΣ Analog-to-Digital Converter with I2C Interface and On-Board Reference, SOIC-14/TSSOP-14
U3, U7, | 2 | MCP4725A0T-E_CH | MCP4725A0T-E_CH | Package_TO_SOT_SMD:SOT-23-6_Handsoldering
U4, U5, | 2 | 2SC5200NS1_E_S | 2SC5200NS1_E_S | footprints:2SC5200NS1_E_S
U6, | 1 | LT1490CN8PBF | LT1490CN8PBF | Package_SO:SOIC-8_3.9x4.9mm_P1.27mm
U8, | 1 | MCP1703A-3302_SOT223 | MCP1703A-3302_SOT223 | Package_TO_SOT_SMD:SOT-223-3_TabPin2 | Low Quiescent Current LDO Regulator, 3.3V, 250mA, Vin<=16V, SOT-223
U9, | 1 | STM32F411RETx | STM32F411RETx | Package_QFP:LQFP-64_10x10mm_P0.5mm | ARM Cortex-M4 MCU, 512KB flash, 128KB RAM, 100MHz, 1.7-3.6V, 50 GPIO, LQFP-64
Y1, | 1 | 24MHz | Crystal | Crystal:Crystal_HC49-U_Vertical | Two pin crystal
Y2, | 1 | 32k768 | Crystal | Crystal:Crystal_C38-LF_D3.0mm_L8.0mm_Horizontal | Two pin crystal

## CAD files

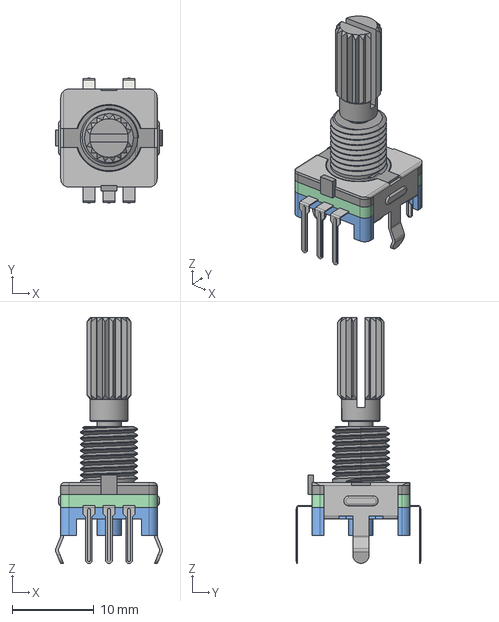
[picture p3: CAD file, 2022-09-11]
PCB/MainBoard/3D/EC11_Rotary_Encoder_Switched.step
13.1 x 15.3 x 30.1 mm

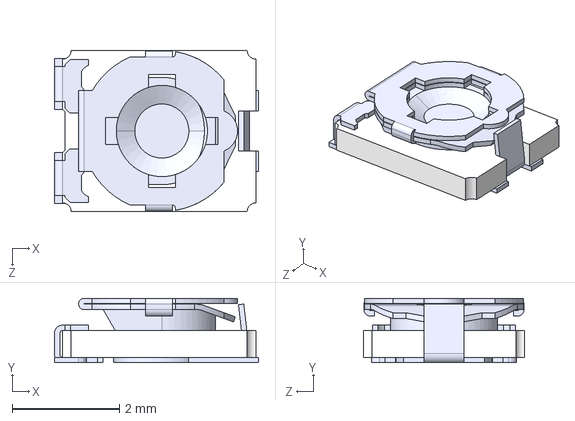
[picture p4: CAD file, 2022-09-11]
PCB/MainBoard/TC33X-2-102E.STEP
3.80 x 1.20 x 3.00 mm

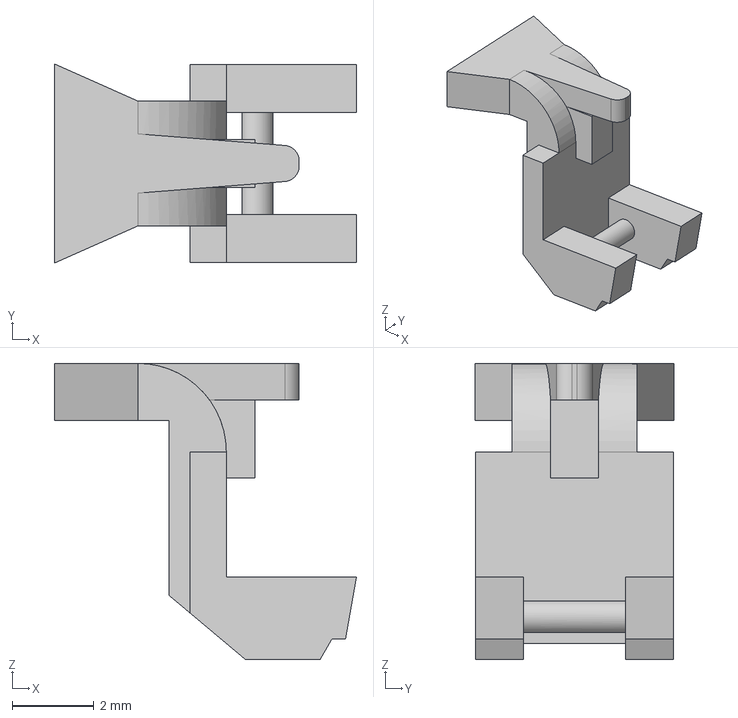
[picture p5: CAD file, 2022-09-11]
PCB/MainBoard/3D/latch-header-452-series.stp
7.37 x 4.86 x 7.23 mm

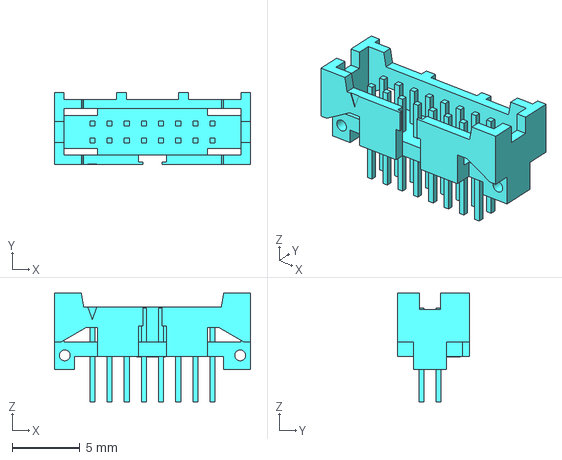
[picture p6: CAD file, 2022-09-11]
PCB/MainBoard/3D/45216-6X02.stp
14.5 x 5.33 x 8.03 mm

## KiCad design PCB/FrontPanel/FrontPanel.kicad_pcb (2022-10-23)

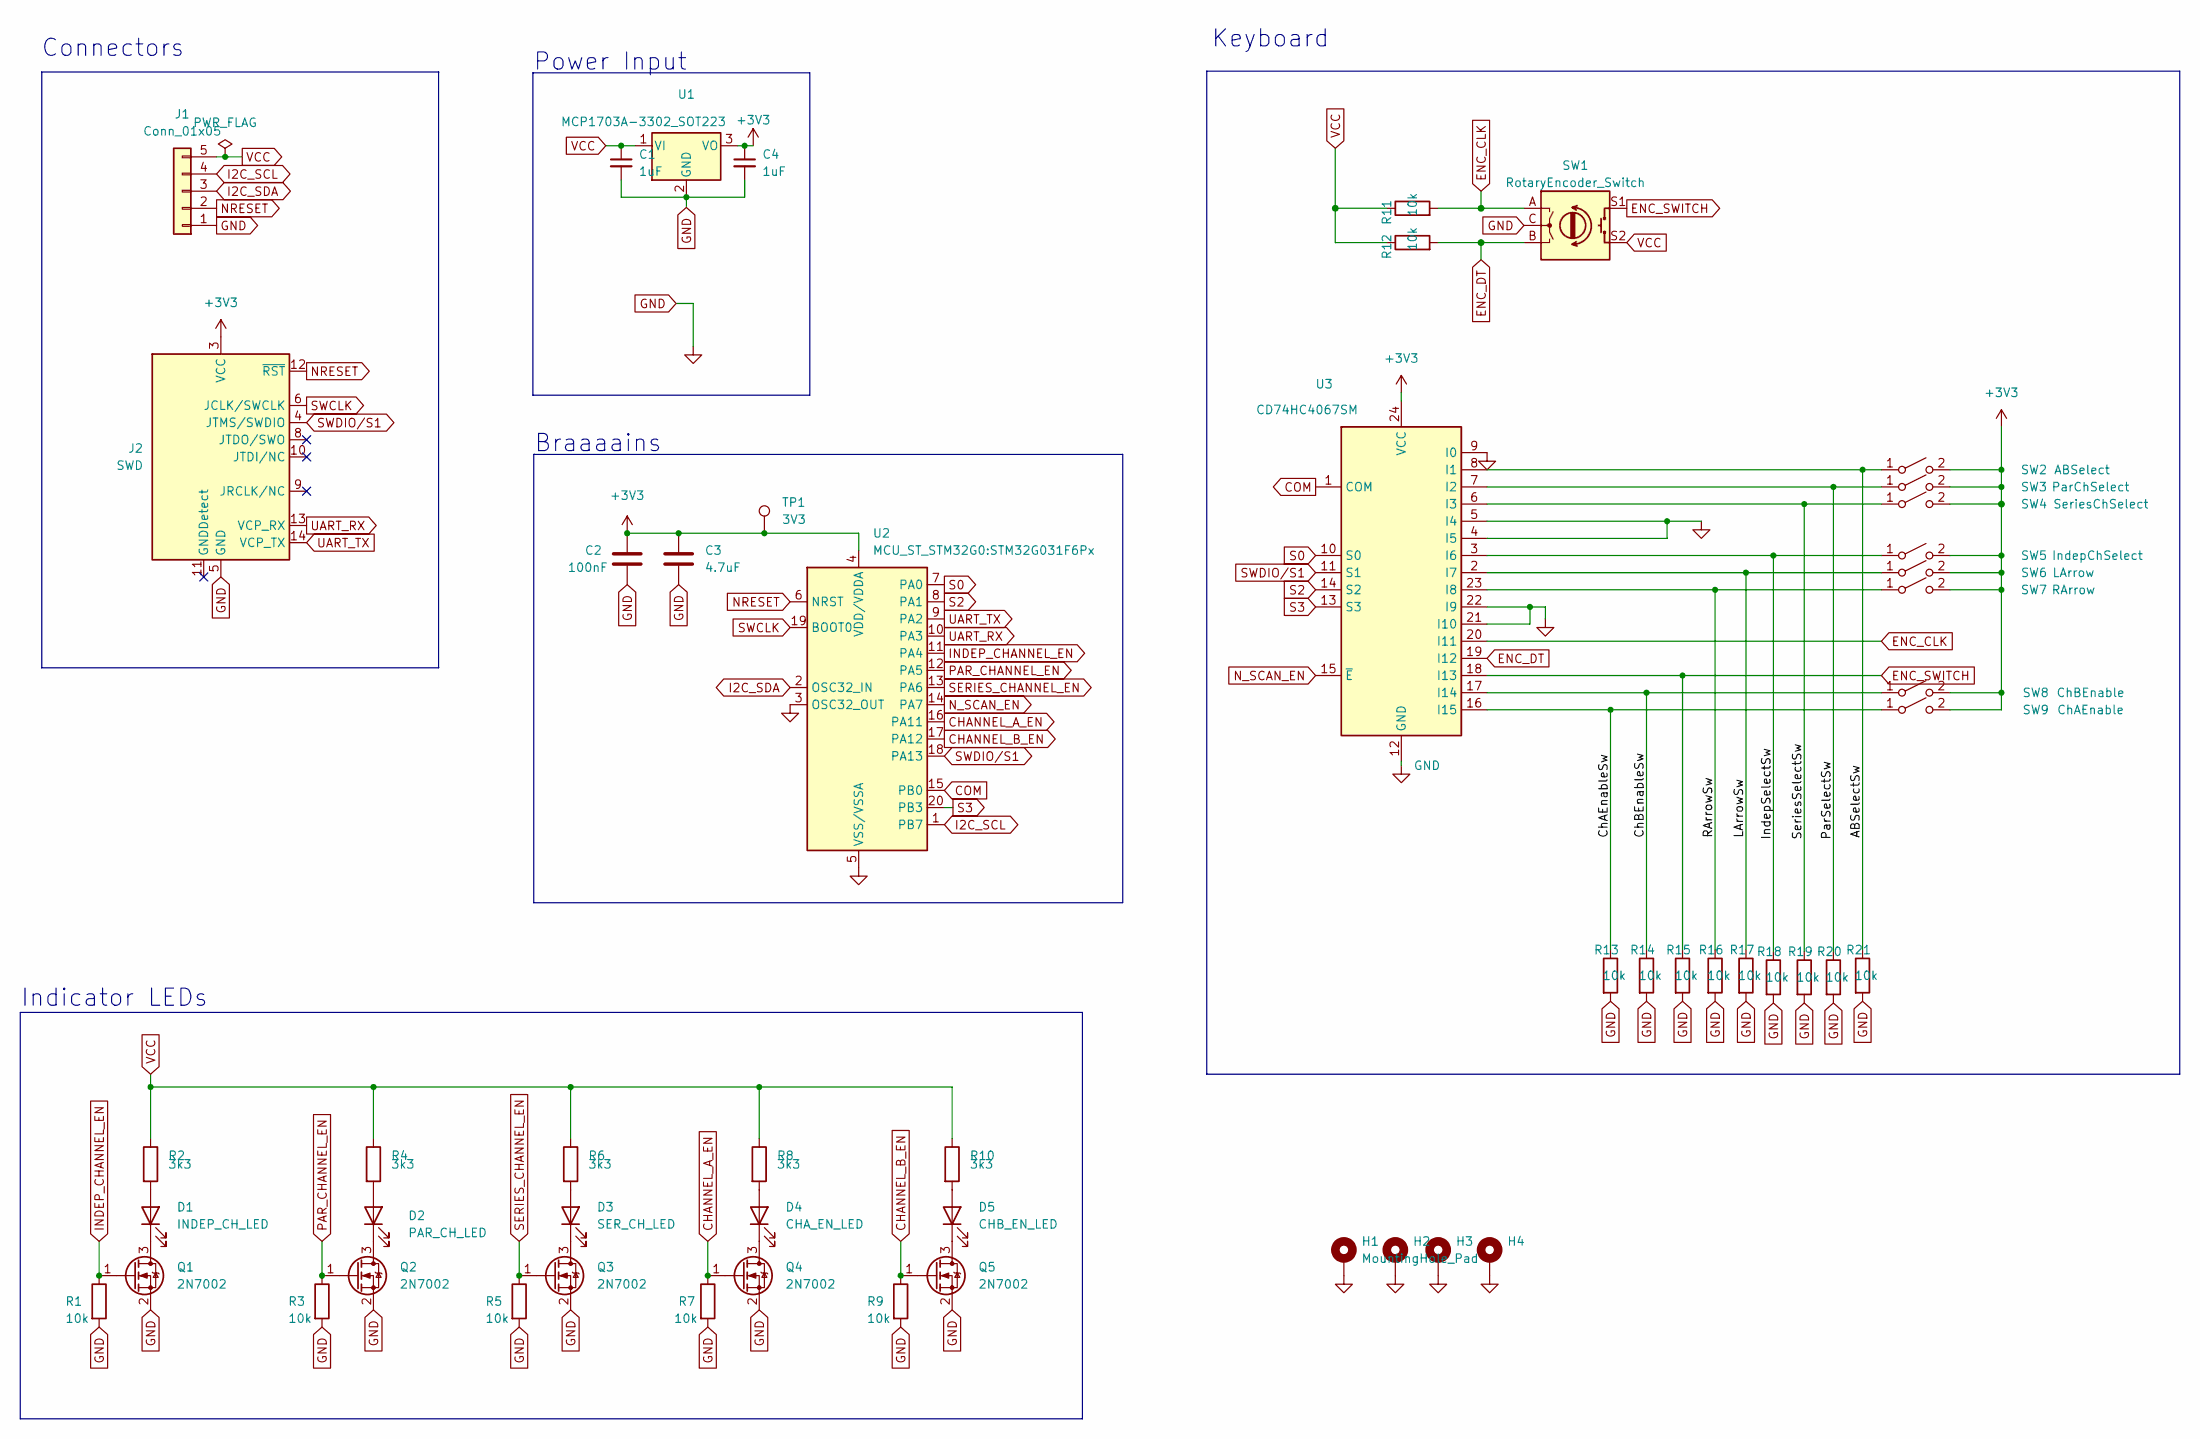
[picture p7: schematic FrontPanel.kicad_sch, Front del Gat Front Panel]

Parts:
C1, C4: 1uF; C_0805_2012Metric
C2: 100nF; C_0805_2012Metric_Pad1.18x1.45mm_HandSolder
C3: 4.7uF; C_0805_2012Metric_Pad1.18x1.45mm_HandSolder; JLC 0603
D1: INDEP_CH_LED; LED_0805_2012Metric_Pad1.15x1.40mm_HandSolder
D2: PAR_CH_LED; LED_0805_2012Metric_Pad1.15x1.40mm_HandSolder
D3: SER_CH_LED; LED_0805_2012Metric_Pad1.15x1.40mm_HandSolder
D4: CHA_EN_LED; LED_0805_2012Metric_Pad1.15x1.40mm_HandSolder
D5: CHB_EN_LED; LED_0805_2012Metric_Pad1.15x1.40mm_HandSolder
H1: MountingHole_Pad; MountingHole_3.2mm_M3_Pad_Via
H2, H3, H4: MountingHole_3.2mm_M3_Pad_Via
J1: Conn_01x05; Molex_KK-254_AE-6410-05A_1x05_P2.54mm_Vertical
J2: SWD; PinHeader_2x07_P1.27mm_Vertical_SMD
Q1, Q2, Q3, Q4, Q5: 2N7002; SOT-23
R1, R3, R5, R7, R9, R11, R12, R13, R14, R15, R16, R17, R18, R19, R20, R21: 10k; R_0805_2012Metric_Pad1.20x1.40mm_HandSolder
R2, R4, R6, R8, R10: 3k3; R_0805_2012Metric_Pad1.20x1.40mm_HandSolder
SW1: RotaryEncoder_Switch; RotaryEncoder_Alps_EC11E-Switch_Vertical_H20mm
SW2: ABSelect; SW_PUSH_6mm
SW3: ParChSelect; SW_PUSH_6mm
SW4: SeriesChSelect; SW_PUSH_6mm
SW5: IndepChSelect; SW_PUSH_6mm
SW6: LArrow; SW_PUSH_6mm
SW7: RArrow; SW_PUSH_6mm
SW8: ChBEnable; SW_PUSH_6mm
SW9: ChAEnable; SW_PUSH_6mm
TP1: 3V3; TestPoint_THTPad_D2.0mm_Drill1.0mm
U1: MCP1703A-3302_SOT223; SOT-223-3_TabPin2
U2: MCU_ST_STM32G0:STM32G031F6Px; TSSOP-20_4.4x6.5mm_P0.65mm
U3: CD74HC4067SM; SSOP-24_5.3x8.2mm_P0.65mm

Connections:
+3V3: C2.1, C3.1, C4.1, J2.3 (VCC), SW2.2 (B), SW3.2 (B), SW4.2 (B), SW5.2 (B), SW6.2 (B), SW7.2 (B), SW8.2 (B), SW9.2 (B), TP1.1, U1.3 (VO), U2.4 (VDD/VDDA), U3.24 (VCC)
/ABSelectSw: R21.1, SW2.1 (A), U3.8 (I1)
/ChAEnableSw: R13.1, SW9.1 (A), U3.16 (I15)
/ChBEnableSw: R14.1, SW8.1 (A), U3.17 (I14)
/IndepSelectSw: R18.1, SW5.1 (A), U3.3 (I6)
/LArrowSw: R17.1, SW6.1 (A), U3.2 (I7)
/ParSelectSw: R20.1, SW3.1 (A), U3.7 (I2)
/RArrowSw: R16.1, SW7.1 (A), U3.23 (I8)
/SeriesSelectSw: R19.1, SW4.1 (A), U3.6 (I3)
CHANNEL_A_EN: Q4.1 (G), R7.1, U2.16 (PA11)
CHANNEL_B_EN: Q5.1 (G), R9.1, U2.17 (PA12)
COM: U2.15 (PB0), U3.1 (COM)
ENC_CLK: R11.2, SW1.A, U3.20 (I11)
ENC_DT: R12.2, SW1.B, U3.19 (I12)
ENC_SWITCH: R15.1, SW1.S1, U3.18 (I13)
GND: C1.2, C2.2, C3.2, C4.2, H1.1, H2.1, H3.1, H4.1, J1.1, J2.5 (GND), J2.7 (GND), Q1.2 (S), Q2.2 (S), Q3.2 (S), Q4.2 (S), Q5.2 (S), R1.2, R3.2, R5.2, R7.2, R9.2, R13.2, R14.2, R15.2, R16.2, R17.2, R18.2, R19.2, R20.2, R21.2, SW1.C, U1.2 (GND), U2.3 (OSC32_OUT), U2.5 (VSS/VSSA), U3.4 (I5), U3.5 (I4), U3.9 (I0), U3.12 (GND), U3.21 (I10), U3.22 (I9)
I2C_SCL: J1.4, U2.1 (PB7)
I2C_SDA: J1.3, U2.2 (OSC32_IN)
INDEP_CHANNEL_EN: Q1.1 (G), R1.1, U2.11 (PA4)
NRESET: J1.2, J2.12 (~RST), U2.6 (NRST)
N_SCAN_EN: U2.14 (PA7), U3.15 (~E)
unnamed: D1.1 (K), Q1.3 (D)
unnamed: D1.2 (A), R2.2
unnamed: D2.1 (K), Q2.3 (D)
unnamed: D2.2 (A), R4.2
unnamed: D3.1 (K), Q3.3 (D)
unnamed: D3.2 (A), R6.2
unnamed: D4.1 (K), Q4.3 (D)
unnamed: D4.2 (A), R8.2
unnamed: D5.1 (K), Q5.3 (D)
unnamed: D5.2 (A), R10.2
PAR_CHANNEL_EN: Q2.1 (G), R3.1, U2.12 (PA5)
S0: U2.7 (PA0), U3.10 (S0)
S2: U2.8 (PA1), U3.14 (S2)
S3: U2.20 (PB3), U3.13 (S3)
SERIES_CHANNEL_EN: Q3.1 (G), R5.1, U2.13 (PA6)
SWCLK: J2.6 (JCLK/SWCLK), U2.19 (BOOT0)
SWDIO/S1: J2.4 (JTMS/SWDIO), U2.18 (PA13), U3.11 (S1)
UART_RX: J2.13 (VCP_RX), U2.10 (PA3)
UART_TX: J2.14 (VCP_TX), U2.9 (PA2)
VCC: C1.1, J1.5, R2.1, R4.1, R6.1, R8.1, R10.1, R11.1, R12.1, SW1.S2, U1.1 (VI)

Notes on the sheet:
Keyboard
Braaaains
Indicator LEDs
Power Input
Connectors

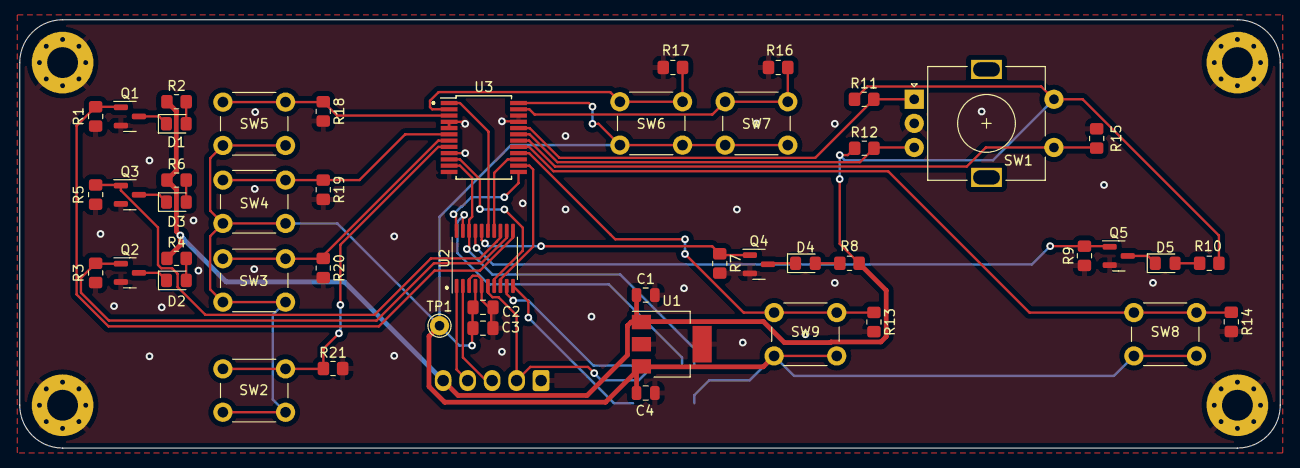
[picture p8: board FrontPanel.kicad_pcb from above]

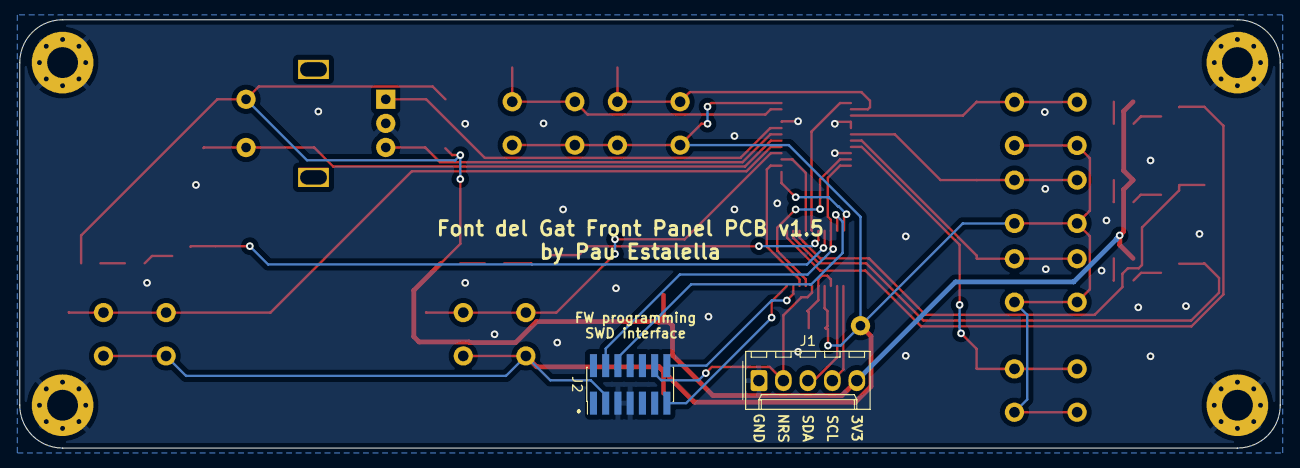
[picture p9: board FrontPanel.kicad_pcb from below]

Board: 2 copper layers, 130.8 x 44.5 mm, 54 parts (2 on the bottom side), 41 nets.

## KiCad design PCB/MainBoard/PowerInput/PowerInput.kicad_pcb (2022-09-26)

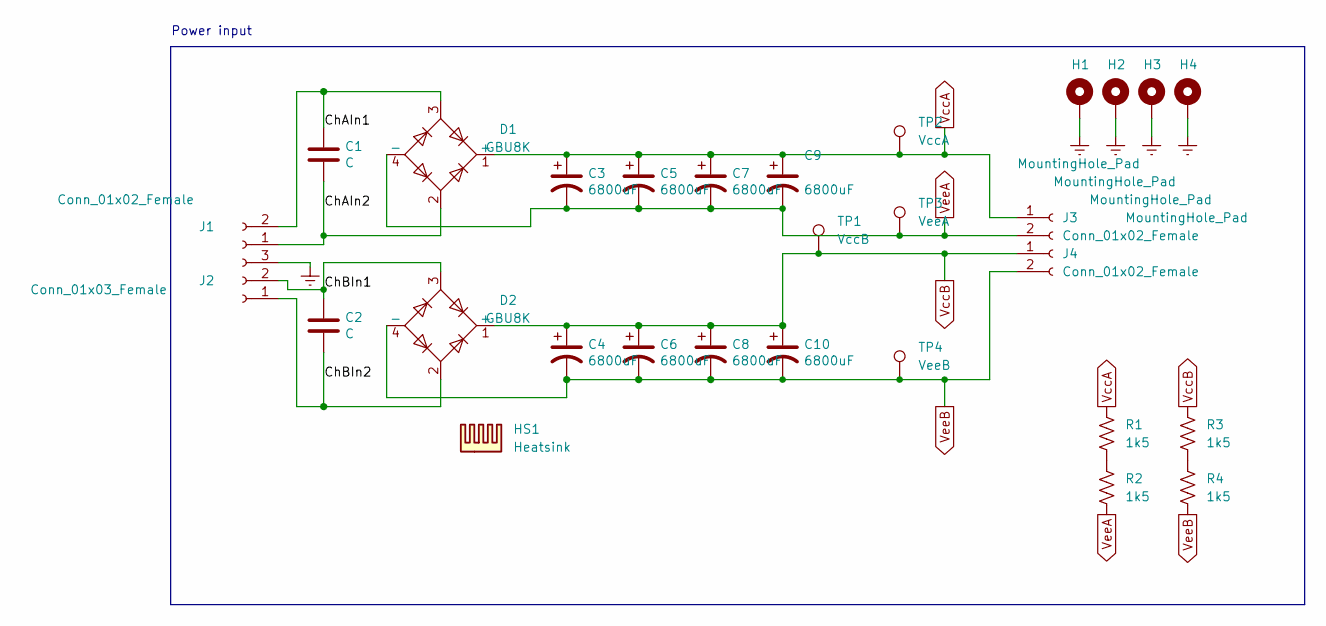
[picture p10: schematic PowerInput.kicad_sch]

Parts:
C1, C2: C; C_Rect_L18.0mm_W6.0mm_P15.00mm_FKS3_FKP3
C3, C4, C5, C6, C7, C8, C9, C10: 6800uF; CP_Radial_D30.0mm_P10.00mm_SnapIn
D1, D2: GBU8K; Diode_Bridge_Vishay_GBU
H1, H2, H3, H4: MountingHole_Pad; MountingHole_4.3mm_M4_Pad_Via
HS1: Heatsink; Heatsink_custom_85x4mm_3xFixationM3
J1, J3, J4: Conn_01x02_Female; PhoenixContact_MSTBVA_2,5_2-G-5,08_1x02_P5.08mm_Vertical
J2: Conn_01x03_Female; PhoenixContact_MSTBVA_2,5_3-G-5,08_1x03_P5.08mm_Vertical
R1, R2, R3, R4: 1k5; R_Axial_DIN0414_L11.9mm_D4.5mm_P20.32mm_Horizontal
TP1: VccB; TestPoint_Pad_D2.0mm
TP2: VccA; TestPoint_Pad_D2.0mm
TP3: VeeA; TestPoint_Pad_D2.0mm
TP4: VeeB; TestPoint_Pad_D2.0mm

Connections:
/ChAIn1: C1.1, D1.3, J1.2
/ChAIn2: C1.2, D1.2, J1.1
/ChBIn1: C2.1, D2.3, J2.2
/ChBIn2: C2.2, D2.2, J2.1
Earth: H1.1, H2.1, H3.1, H4.1, J2.3
unnamed: R1.2, R2.1
unnamed: R3.2, R4.1
VccA: C3.1, C5.1, C7.1, C9.1, D1.1 (+), J3.1, R1.1, TP2.1
VccB: C4.1, C6.1, C8.1, C10.1, D2.1 (+), J4.1, R3.1, TP1.1
VeeA: C3.2, C5.2, C7.2, C9.2, D1.4 (-), J3.2, R2.2, TP3.1
VeeB: C4.2, C6.2, C8.2, C10.2, D2.4 (-), J4.2, R4.2, TP4.1

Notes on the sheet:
Power input

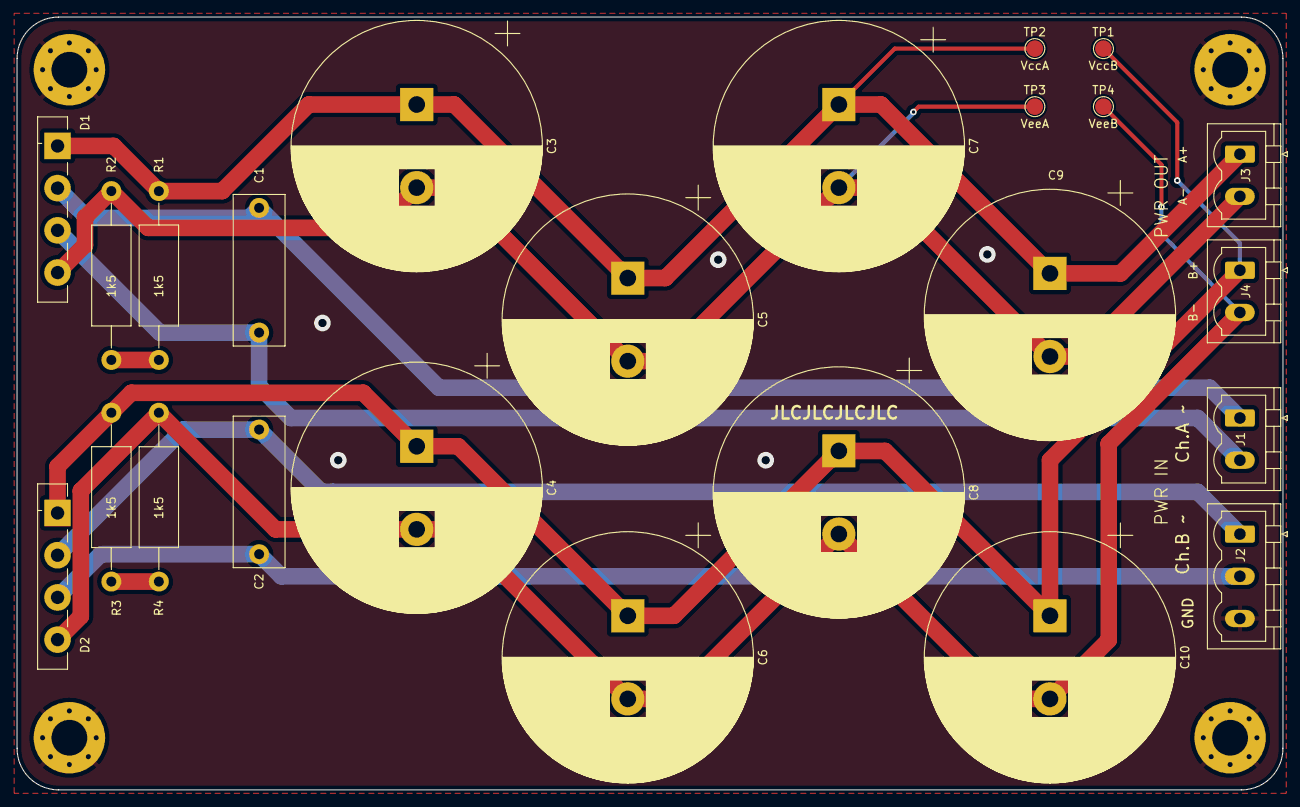
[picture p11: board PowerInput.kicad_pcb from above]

Board: 2 copper layers, 152.3 x 93.0 mm, 29 parts (0 on the bottom side), 11 nets.

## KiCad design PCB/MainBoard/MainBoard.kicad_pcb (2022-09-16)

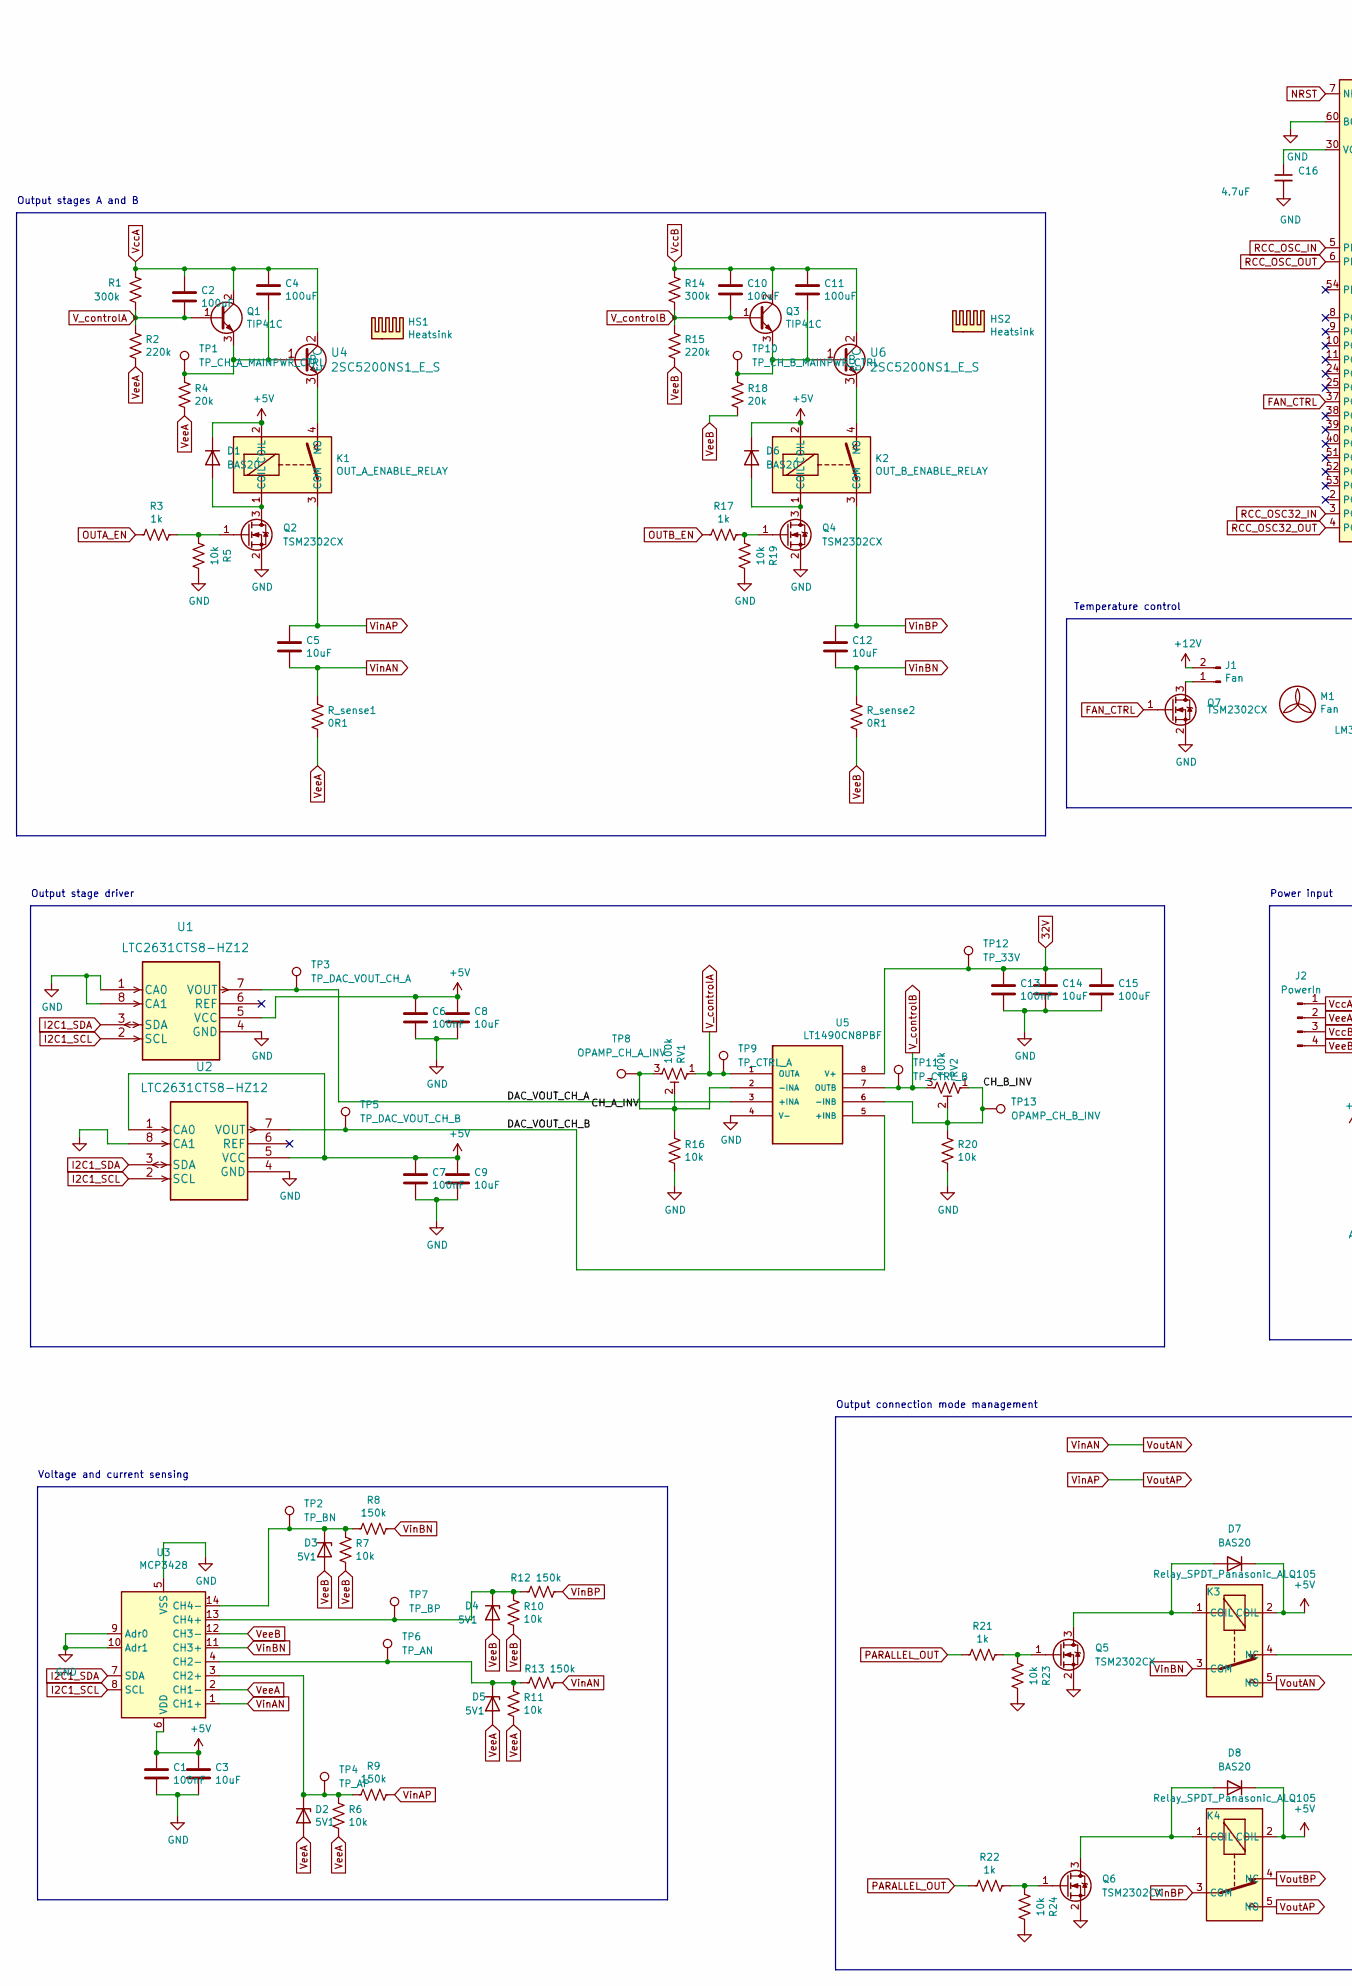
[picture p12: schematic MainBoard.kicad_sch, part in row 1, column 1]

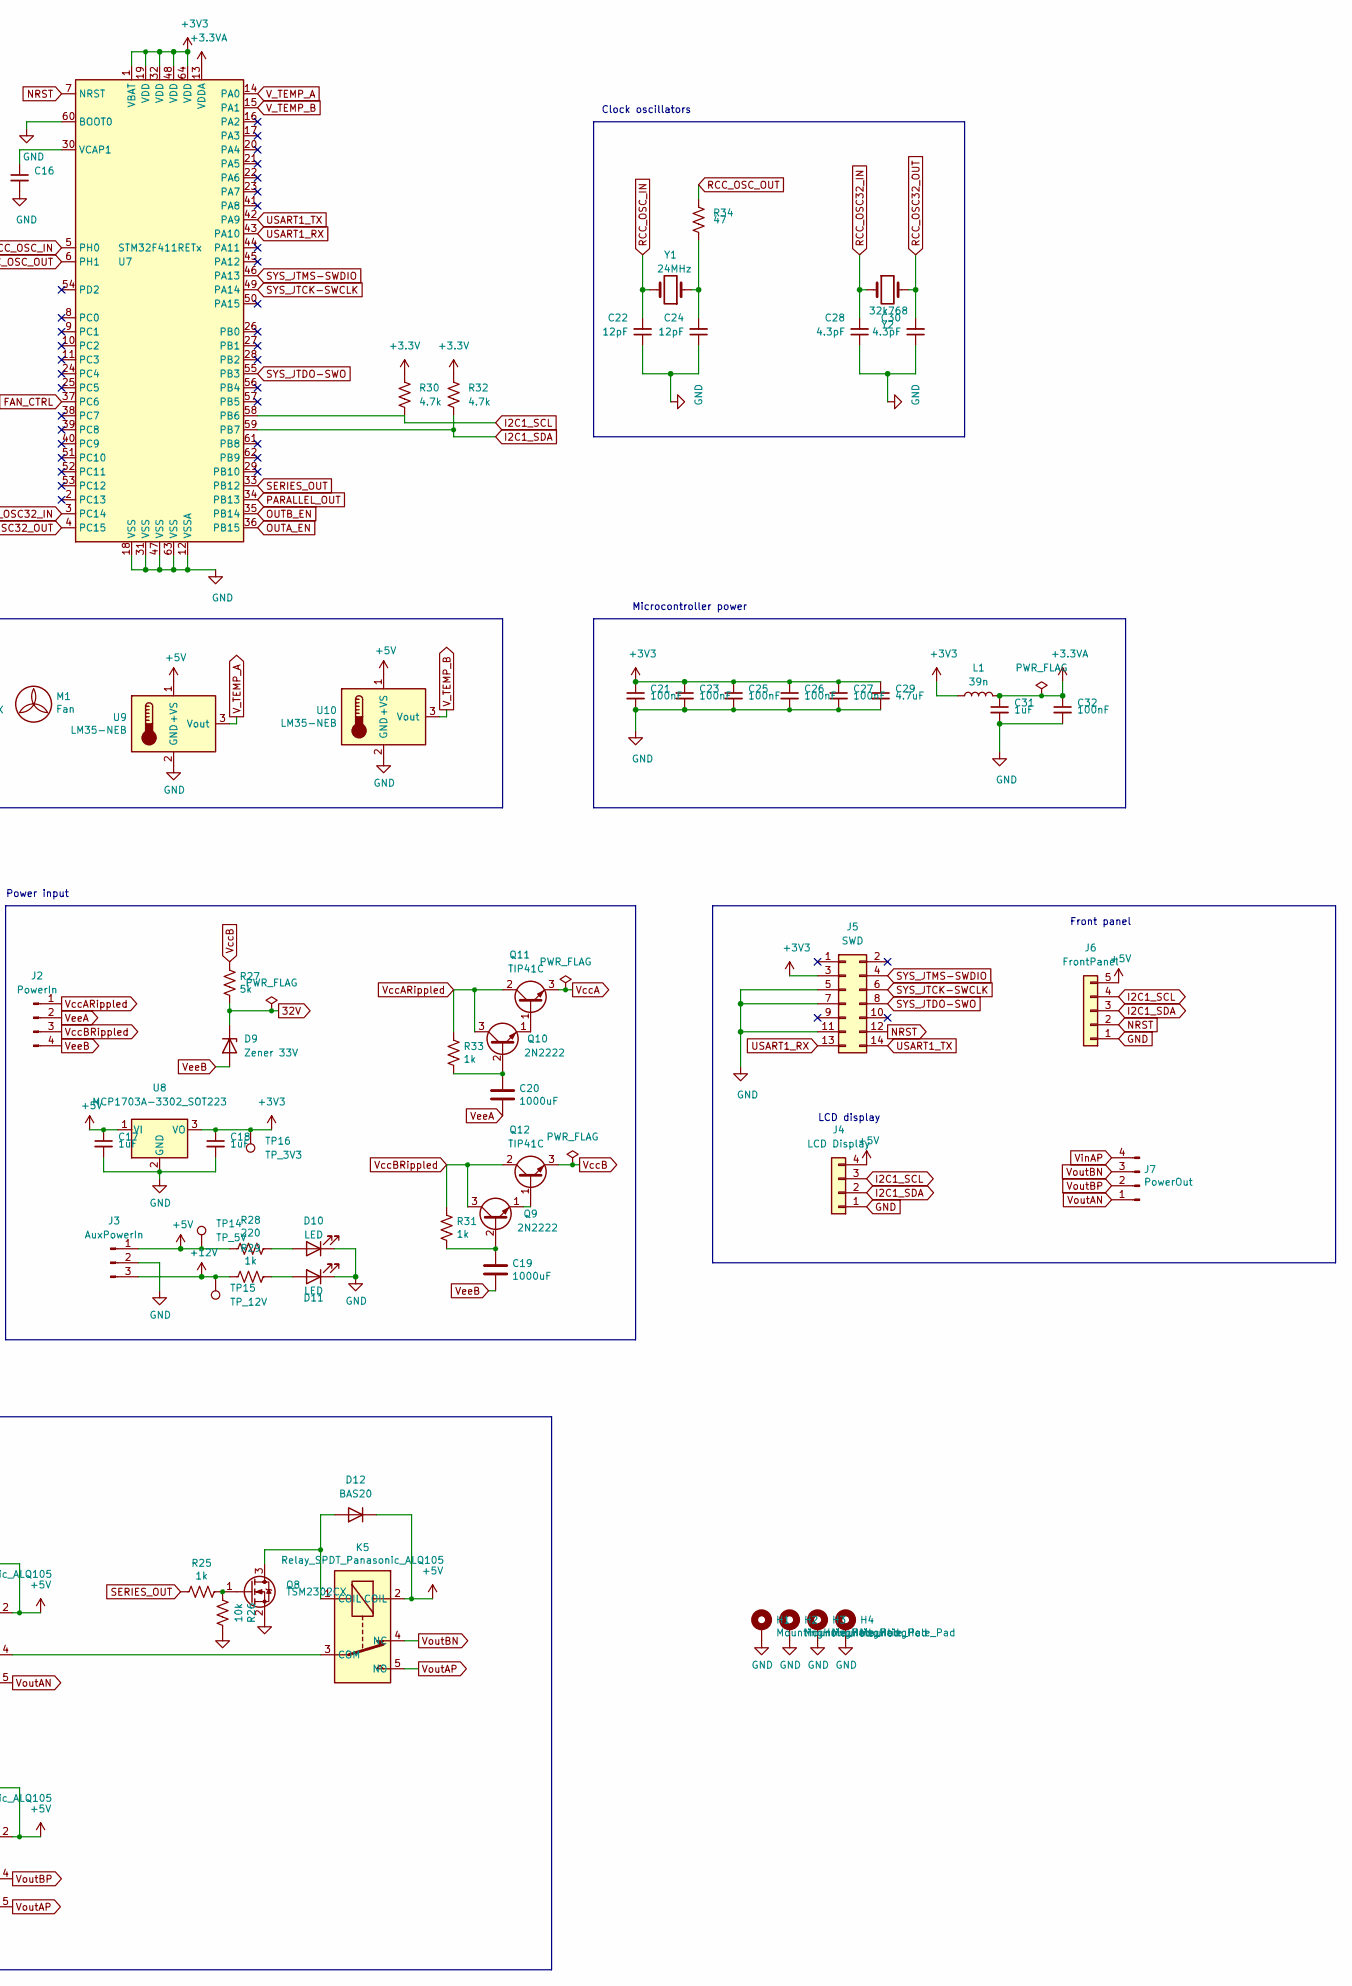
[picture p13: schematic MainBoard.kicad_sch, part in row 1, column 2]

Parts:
C1, C6, C7, C13, C21, C23, C25, C26, C27, C32: 100nF; C_0603_1608Metric_Pad1.08x0.95mm_HandSolder; LCSC C14663
C2, C4, C10, C11, C15: 100uF; CP_Radial_D8.0mm_P3.80mm
C3, C8, C9: 10uF; C_1206_3216Metric_Pad1.33x1.80mm_HandSolder; LCSC C13585
C5, C12: 10uF; CP_Radial_D5.0mm_P2.00mm
C14: 10uF; C_1206_3216Metric_Pad1.42x1.75mm_HandSolder; LCSC C13585
C16, C29: 4.7uF; C_0603_1608Metric_Pad1.08x0.95mm_HandSolder; LCSC C19666
C17, C18: 1uF; C_0805_2012Metric; LCSC C28323
C19, C20: 1000uF; CP_Radial_D16.0mm_P7.50mm
C22, C24: 12pF; C_0603_1608Metric_Pad1.08x0.95mm_HandSolder
C28, C30: 4.3pF; C_0603_1608Metric_Pad1.08x0.95mm_HandSolder
C31: 1uF; C_1206_3216Metric_Pad1.33x1.80mm_HandSolder; LCSC C1848
D1, D6, D7, D8, D12: BAS20; SOT-23
D2, D3, D4, D5: 5V1; D_SOD-123
D9: Zener 33V; D_DO-35_SOD27_P10.16mm_Horizontal
D10, D11: LED; LED_0805_2012Metric_Pad1.15x1.40mm_HandSolder
H1, H2, H3, H4: MountingHole_Pad; MountingHole_4.3mm_M4_Pad_Via
HS1, HS2: Heatsink; Heatsink_100x36mm_2xfixations_HorizAirflow
J1: Fan; JST_EH_B2B-EH-A_1x02_P2.50mm_Vertical
J2: PowerIn; PhoenixContact_MSTBVA_2,5_4-G-5,08_1x04_P5.08mm_Vertical
J3: AuxPowerIn; PhoenixContact_MSTBVA_2,5_3-G-5,08_1x03_P5.08mm_Vertical
J4: LCD Display; Molex_KK-254_AE-6410-04A_1x04_P2.54mm_Vertical
J5: SWD; PinHeader_2x07_P1.27mm_Vertical_SMD
J6: FrontPanel; Molex_KK-254_AE-6410-05A_1x05_P2.54mm_Vertical
J7: PowerOut; PhoenixContact_MSTBVA_2,5_4-G-5,08_1x04_P5.08mm_Vertical
K1: OUT_A_ENABLE_RELAY; Relay_SPST_Panasonic_ALQ305
K2: OUT_B_ENABLE_RELAY; Relay_SPST_Panasonic_ALQ305
K3, K4, K5: Relay_SPDT_Panasonic_ALQ105; Relay_SPDT_Panasonic-ALQ105
L1: 39n; L_0805_2012Metric_Pad1.15x1.40mm_HandSolder
M1: Fan; Fan_Orion_OD7020_vertical
Q1, Q3, Q11, Q12: TIP41C; TO-220-3_Vertical
Q2, Q4, Q5, Q6, Q7, Q8: TSM2302CX; SOT-23
Q9, Q10: 2N2222; TO-92_HandSolder
R1, R14: 300k; R_0805_2012Metric_Pad1.20x1.40mm_HandSolder; LCSC C17616
R2, R15: 220k; R_0805_2012Metric_Pad1.20x1.40mm_HandSolder; LCSC C17556
R3, R17, R21, R22, R25, R29, R31, R33: 1k; R_0805_2012Metric_Pad1.20x1.40mm_HandSolder; LCSC C17513
R4, R18: 20k; R_0805_2012Metric_Pad1.20x1.40mm_HandSolder; LCSC C4328
R5, R6, R7, R10, R11, R16, R19, R20, R23, R24, R26: 10k; R_0805_2012Metric_Pad1.20x1.40mm_HandSolder; LCSC C17414
R8, R9, R12, R13: 150k; R_0805_2012Metric_Pad1.20x1.40mm_HandSolder; LCSC C17470
R27: 5k; R_Axial_DIN0207_L6.3mm_D2.5mm_P10.16mm_Horizontal
R28: 220; R_0805_2012Metric_Pad1.20x1.40mm_HandSolder; LCSC C17557
R30, R32: 4.7k; R_0805_2012Metric_Pad1.20x1.40mm_HandSolder; LCSC C17673
R34: 47; R_0805_2012Metric_Pad1.20x1.40mm_HandSolder; LCSC C17714
RV1, RV2: 100k; Potentiometer_Panasonic_EVM1D_Vertical
R_sense1, R_sense2: 0R1; R_Bare_Metal_Element_L21.3mm_W4.8mm_P20.30mm
TP1: TP_CH_A_MAINPWR_CTRL; TestPoint_THTPad_D2.0mm_Drill1.0mm
TP2: TP_BN; TestPoint_THTPad_D2.0mm_Drill1.0mm
TP3: TP_DAC_VOUT_CH_A; TestPoint_THTPad_D2.0mm_Drill1.0mm
TP4: TP_AP; TestPoint_THTPad_D2.0mm_Drill1.0mm
TP5: TP_DAC_VOUT_CH_B; TestPoint_THTPad_D2.0mm_Drill1.0mm
TP6: TP_AN; TestPoint_THTPad_D2.0mm_Drill1.0mm
TP7: TP_BP; TestPoint_THTPad_D2.0mm_Drill1.0mm
TP8: OPAMP_CH_A_INV; TestPoint_THTPad_D2.0mm_Drill1.0mm
TP9: TP_CTRL_A; TestPoint_THTPad_D2.0mm_Drill1.0mm
TP10: TP_CH_B_MAINPWR_CTRL; TestPoint_THTPad_D2.0mm_Drill1.0mm
TP11: TP_CTRL_B; TestPoint_THTPad_D2.0mm_Drill1.0mm
TP12: TP_33V; TestPoint_THTPad_D2.0mm_Drill1.0mm
TP13: OPAMP_CH_B_INV; TestPoint_THTPad_D2.0mm_Drill1.0mm
TP14: TP_5V; TestPoint_THTPad_D2.0mm_Drill1.0mm
TP15: TP_12V; TestPoint_THTPad_D2.0mm_Drill1.0mm
TP16: TP_3V3; TestPoint_THTPad_D2.0mm_Drill1.0mm
U1, U2: LTC2631CTS8-HZ12; ltc2631cts8-hz12-trmpbf
U3: MCP3428; SOIC-14_3.9x8.7mm_P1.27mm; LCSC C560166
U4, U6: 2SC5200NS1_E_S
U5: LT1490CN8PBF; SOIC-8_3.9x4.9mm_P1.27mm; LCSC C664001
U7: STM32F411RETx; LQFP-64_10x10mm_P0.5mm; LCSC C94355
U8: MCP1703A-3302_SOT223; SOT-223-3_TabPin2
U9, U10: LM35-NEB; TO-220-3_Vertical
Y1: 24MHz; Crystal_HC49-U_Vertical
Y2: 32k768; Crystal_C38-LF_D3.0mm_L8.0mm_Horizontal

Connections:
32V: C13.1, C14.1, C15.1, D9.1 (K), R27.2, TP12.1, U5.8 (V+)
+3.3VA: C31.1, C32.1, L1.2, U7.13 (VDDA)
+5V: C1.1, C3.1, C6.1, C7.1, C8.1, C9.1, C17.1, D1.3 (K), D6.3 (K), D7.3 (K), D8.3 (K), D12.3 (K), J3.1, J4.4, J6.5, K1.2 (COIL), K2.2 (COIL), K3.2 (COIL), K4.2 (COIL), K5.2 (COIL), R28.2, TP14.1, U1.5 (VCC), U2.1 (CA0), U2.5 (VCC), U3.6 (VDD), U8.1 (VI), U9.1 (+VS), U10.1 (+VS)
+12V: J1.2, J3.3, R29.2, TP15.1
/CH_A_INV: R16.1, RV1.2, RV1.3, TP8.1, U5.2 (-INA)
/CH_B_INV: R20.1, RV2.1, RV2.2, TP13.1, U5.6 (-INB)
/DAC_VOUT_CH_A: TP3.1, U1.7 (VOUT), U5.3 (+INA)
/DAC_VOUT_CH_B: TP5.1, U2.7 (VOUT), U5.5 (+INB)
FAN_CTRL: Q7.1 (G), U7.37 (PC6)
I2C1_SCL: J4.3, J6.4, R30.1, U1.2 (SCL), U2.2 (SCL), U3.8 (SCL), U7.58 (PB6)
I2C1_SDA: J4.2, J6.3, R32.2, U1.3 (SDA), U2.3 (SDA), U3.7 (SDA), U7.59 (PB7)
NRST: J5.12, J6.2, U7.7 (NRST)
unnamed: C4.2, Q1.3 (E), R4.1, TP1.1, U4.1 (B)
unnamed: C11.2, Q3.3 (E), R18.1, TP10.1, U6.1 (B)
unnamed: C16.1, U7.30 (VCAP1)
unnamed: C19.1, Q9.2 (B), R31.2
unnamed: C20.1, Q10.2 (B), R33.2
unnamed: C24.2, R34.2, Y1.1
unnamed: D1.1 (A), K1.1 (COIL), Q2.3 (D)
unnamed: D2.1 (K), R6.1, R9.2, TP4.1, U3.3 (CH2+)
unnamed: D3.1 (K), R7.1, R8.2, TP2.1, U3.14 (CH4-)
unnamed: D4.1 (K), R10.1, R12.2, TP7.1, U3.13 (CH4+)
unnamed: D5.1 (K), R11.1, R13.2, TP6.1, U3.4 (CH2-)
unnamed: D6.1 (A), K2.1 (COIL), Q4.3 (D)
unnamed: D7.1 (A), K3.1 (COIL), Q5.3 (D)
unnamed: D8.1 (A), K4.1 (COIL), Q6.3 (D)
unnamed: D10.2 (A), R28.1
unnamed: D11.2 (A), R29.1
unnamed: D12.1 (A), K5.1 (COIL), Q8.3 (D)
unnamed: J1.1, Q7.3 (D)
unnamed: K1.4 (NO), U4.3 (E)
unnamed: K2.4 (NO), U6.3 (E)
unnamed: K3.4 (NC), K5.3 (COM)
unnamed: Q2.1 (G), R3.1, R5.2
unnamed: Q4.1 (G), R17.1, R19.2
unnamed: Q5.1 (G), R21.1, R23.2
unnamed: Q6.1 (G), R22.1, R24.2
unnamed: Q8.1 (G), R25.1, R26.2
unnamed: Q10.1 (E), Q11.1 (B)
unnamed: Q9.1 (E), Q12.1 (B)
OUTA_EN: R3.2, U7.36 (PB15)
OUTB_EN: R17.2, U7.35 (PB14)
PARALLEL_OUT: R21.2, R22.2, U7.34 (PB13)
RCC_OSC32_IN: C28.2, U7.3 (PC14), Y2.1
RCC_OSC32_OUT: C30.2, U7.4 (PC15), Y2.2
RCC_OSC_IN: C22.2, U7.5 (PH0), Y1.2
RCC_OSC_OUT: R34.1, U7.6 (PH1)
SERIES_OUT: R25.2, U7.33 (PB12)
SYS_JTCK-SWCLK: J5.6, U7.49 (PA14)
SYS_JTDO-SWO: J5.8, U7.55 (PB3)
SYS_JTMS-SWDIO: J5.4, U7.46 (PA13)
USART1_RX: J5.13, U7.43 (PA10)
USART1_TX: J5.14, U7.42 (PA9)
V_TEMP_A: U7.14 (PA0), U9.3 (Vout)
V_TEMP_B: U7.15 (PA1), U10.3 (Vout)
V_controlA: C2.2, Q1.1 (B), R1.2, R2.1, RV1.1, TP9.1, U5.1 (OUTA)
V_controlB: C10.2, Q3.1 (B), R14.2, R15.1, RV2.3, TP11.1, U5.7 (OUTB)
VccA: C2.1, C4.1, Q1.2 (C), Q11.3 (E), R1.1, U4.2 (C)
VccARippled: J2.1, Q10.3 (C), Q11.2 (C), R33.1
VccB: C10.1, C11.1, Q3.2 (C), Q12.3 (E), R14.1, R27.1, U6.2 (C)
VccBRippled: J2.3, Q9.3 (C), Q12.2 (C), R31.1
VeeA: C20.2, D2.2 (A), D5.2 (A), J2.2, R2.2, R4.2, R6.2, R11.2, R_sense1.2, U3.2 (CH1-)
VeeB: C19.2, D3.2 (A), D4.2 (A), D9.2 (A), J2.4, R7.2, R10.2, R15.2, R18.2, R_sense2.2, U3.12 (CH3-)
VinAN: C5.2, J7.1, K3.5 (NO), R13.1, R_sense1.1, U3.1 (CH1+)
VinAP: C5.1, J7.4, K1.3 (COM), K4.5 (NO), K5.5 (NO), R9.1
VinBN: C12.2, K3.3 (COM), R8.1, R_sense2.1, U3.11 (CH3+)
VinBP: C12.1, K2.3 (COM), K4.3 (COM), R12.1
VoutBN: J7.3, K5.4 (NC)
VoutBP: J7.2, K4.4 (NC)

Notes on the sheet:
Clock oscillators
Microcontroller power
Power input
Temperature control
Front panel
Output stage driver
Output stages A and B
LCD display
Voltage and current sensing
Output connection mode management

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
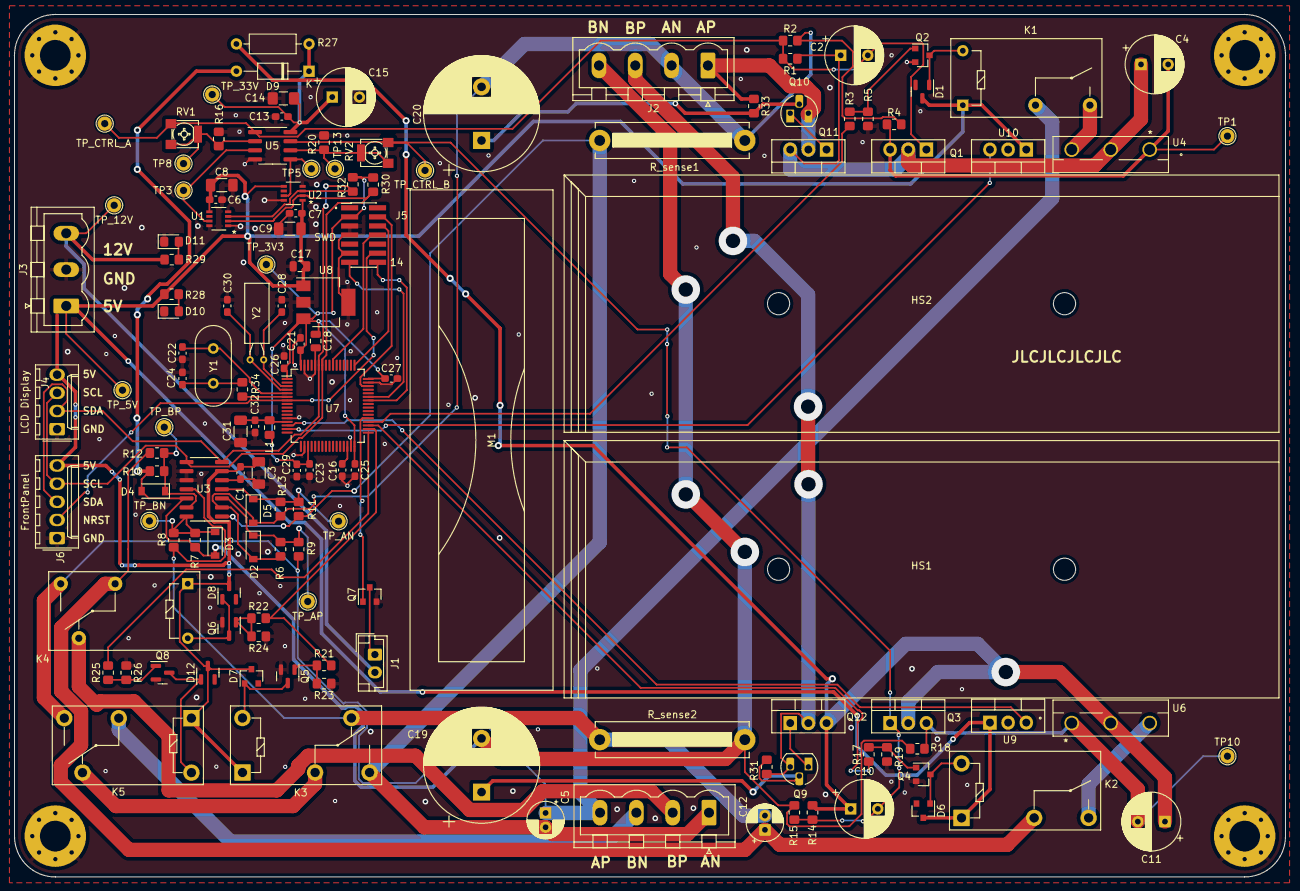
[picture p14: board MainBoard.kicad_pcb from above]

Board: 2 copper layers, 177.8 x 120.7 mm, 142 parts (0 on the bottom side), 71 nets.

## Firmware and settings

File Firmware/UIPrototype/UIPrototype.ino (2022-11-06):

#include "DisplayState.h"

#include <Arduino.h>

uint16_t buttonState;
const int MenuButton = 2;
const int ChAEnButton = 3;
const int ChBEnButton = 4;

DisplayState disp;

void setup()
{
    Serial.begin(115200);
    Serial.println("Front panel test");

    Wire.begin();
    disp.begin();
    buttonState = 0;
    pinMode(MenuButton, INPUT);
    delay(1000);
    disp.updateDisplay();
}

int buttonDelay = 0;

void checkButtons()
{
//    uint8_t fpResponse[2];
    uint16_t fpResponse;

    // Request button state
    Wire.beginTransmission(0x42);
    int result = Wire.write(0x01);
    if (result == 0) {
        Serial.println("Error writing to I2C. Result=0");
    }
    //  * Output   0 .. success
    //  *          1 .. length to long for buffer
    //  *          2 .. address send, NACK received
    //  *          3 .. data send, NACK received
    //  *          4 .. other twi error (lost bus arbitration, bus error, ..)
    //  *          5 .. timeout
    result = Wire.endTransmission();
    if (result != 0) {
        Serial.print("Error writing to I2C. Result=");
        Serial.println(result);
        delay(2000);
        return;
    }
    Wire.requestFrom(0x42, 2);
    fpResponse = Wire.read();
    fpResponse |= Wire.read() << 8;
    // Serial.print("Received from frontPanel: 0x");
    // Serial.println(fpResponse, HEX);

    int MuxPin_GND        = 0b0000000000000000;
    int MuxPin_ABSelect   = 0b0000000000000010;
    int MuxPin_ParSelect  = 0b0000000000000100;
    int MuxPin_SerSelect  = 0b0000000000001000;
    int MuxPin_IndSelect  = 0b0000000001000000;
    int MuxPin_LArrow     = 0b0000000010000000;
    int MuxPin_RArrow     = 0b0000000100000000;
    int MuxPin_ENC_CLK    = 0b0000100000000000;
    int MuxPin_ENC_DT     = 0b0001000000000000;
    int MuxPin_ENC_SWITCH = 0b0010000000000000;
    int MuxPin_CHB_EN     = 0b0100000000000000;
    int MuxPin_CHA_EN     = 0b1000000000000000;

    // Flip the state according to the pressed buttons
    uint16_t newButtonState = fpResponse;
    if (newButtonState != buttonState) {
        if (buttonDelay == 0) {
            // Serial.print("Button state: 0x");
            // Serial.println(newButtonState, HEX);
            if ((buttonState & MuxPin_ABSelect) == 0 && (newButtonState & MuxPin_ABSelect) != 0) {
                Serial.println("Menu pressed");
                disp.menuPressed();
            }
            if ((buttonState & MuxPin_CHA_EN) == 0 && (newButtonState & MuxPin_CHA_EN) != 0) {
                Serial.println("ChAEn pressed");
                disp.chAEnablePressed();
            }
            if ((buttonState & MuxPin_CHB_EN) == 0 && (newButtonState & MuxPin_CHB_EN) != 0) {
                Serial.println("ChBEn pressed");
                disp.chBEnablePressed();
            }
            if ((buttonState & MuxPin_IndSelect) == 0 && (newButtonState & MuxPin_IndSelect) != 0) {
                Serial.println("Independent output pressed");
                disp.independentOutputPressed();
            }
            if ((buttonState & MuxPin_ParSelect) == 0 && (newButtonState & MuxPin_ParSelect) != 0) {
                Serial.println("Parallel output pressed");
                disp.parallelOutputPressed();
            }
            if ((buttonState & MuxPin_SerSelect) == 0 && (newButtonState & MuxPin_SerSelect) != 0) {
                Serial.println("Series output pressed");
                disp.seriesOutputPressed();
            }

            disp.updateDisplay();
            buttonState = newButtonState;
            buttonDelay = 10;
        } else {
            buttonDelay--;
        }
        // buttonState = newButtonState;
        // Wire.beginTransmission(0x42);
        // Wire.write(0x02);
        // Wire.write(ledStatus);
        // Wire.endTransmission();
        // Wire.requestFrom(0x42, 1);
        // Wire.read();
    }
}





void loop()
{
    checkButtons();
}

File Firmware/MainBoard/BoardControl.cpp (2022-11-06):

#include "BoardControl.h"

#include <Arduino.h>

const int PARALLEL_OUT = PB13;
const int SERIES_OUT = PB12;
// const int CHANNEL_A_EN = PA11;
const int CHANNEL_B_EN = PB15;
const int V_TEMP_A = PA0;
const int V_TEMP_B = PA1;
const int FAN_CTRL = PC6;
const int I2C_SDA = PB7;
const int I2C_SCL = PB6;

bool fanRunning = false;
int fanDelay = 0;

BoardControl::BoardControl() :
    mySerial(PA10, PA9),
    outSense(mySerial),
    lcd(0x27, 20, 4) // set the LCD address to 0x27 for a 20 chars and 4 line display
{
}

void BoardControl::begin()
{
    Wire.setSCL(I2C_SCL);
    Wire.setSDA(I2C_SDA);

    mySerial.begin(115200);
    mySerial.println("Board Control Firmware");

    Wire.begin();
//    lcd.begin();

    pinMode(CHANNEL_B_EN, OUTPUT);
    pinMode(PARALLEL_OUT, OUTPUT);
    pinMode(SERIES_OUT, OUTPUT);
    pinMode(FAN_CTRL, OUTPUT);

    digitalWrite(CHANNEL_B_EN, LOW);
    digitalWrite(PARALLEL_OUT, LOW);
    digitalWrite(SERIES_OUT, LOW);
    digitalWrite(FAN_CTRL, LOW);

    outSense.begin();

    // Print a message to the LCD.
    lcd.backlight();
    lcd.setCursor(0,1);
    lcd.print("La Font del Gat v1.0");
    lcd.setCursor(1,2);
    lcd.print("(c) Pau Estalella");
    delay(3000);
    lcd.clear();
}

void BoardControl::checkFan()
{
    String msgLine;
    char tempMsgLine[20];

    int tempSensorValueA = analogRead(V_TEMP_A);
    int tempSensorValueB = analogRead(V_TEMP_B);

    int tempA = (tempSensorValueA*22)/79;
    int tempB = (tempSensorValueB*22)/79;

    lcd.setCursor(0,0);
    msgLine = "TA: " + String(tempA);
    msgLine.toCharArray(tempMsgLine, 20);
    lcd.print(tempMsgLine);
    lcd.setCursor(10,0);
    msgLine = "TB: " + String(tempB);
    msgLine.toCharArray(tempMsgLine, 20);
    lcd.print(tempMsgLine);
    bool shouldFanRun = (tempA > 30 || tempB > 30);
    if (fanDelay == 0) {
        if (shouldFanRun != fanRunning) {
            fanRunning = shouldFanRkun;
            fanDelay = 50;
            digitalWrite(FAN_CTRL, fanRunning);
        }
    } else {
        fanDelay--;
    }
}

void BoardControl::changeOutputMode(OutputMode newOutputState)
{
    // Disable relays first, short-circuits are dangerous
    digitalWrite(PARALLEL_OUT, LOW);
    digitalWrite(SERIES_OUT, LOW);
    // Wait for relays to stabilize
    delay(50);
    // Change to new mode
    switch (newOutputState) {
        case MODE_INDEPENDENT:
            break;
        case MODE_PARALLEL:
            digitalWrite(PARALLEL_OUT, HIGH);
            break;
        case MODE_SERIES:
            digitalWrite(SERIES_OUT, HIGH);
            break;
    }
}

int buttonState = 0;
int buttonFlipDelay = 0;
uint8_t ledStatus = 0;

void BoardControl::checkCommands()
{
//    uint8_t fpResponse[2];
    uint16_t fpResponse;

    // Request button state
    Wire.beginTransmission(0x42);
    int result = Wire.write(0x01);
    if (result == 0) {
        mySerial.println("Error writing to I2C. Result=0");
    }
    //  * Output   0 .. success
    //  *          1 .. length to long for buffer
    //  *          2 .. address send, NACK received
    //  *          3 .. data send, NACK received
    //  *          4 .. other twi error (lost bus arbitration, bus error, ..)
    //  *          5 .. timeout
    result = Wire.endTransmission();
    if (result != 0) {
        mySerial.print("Error writing to I2C. Result=");
        mySerial.println(result);
        delay(2000);
        return;
    }
    Wire.requestFrom(0x42, 2);
    fpResponse = Wire.read();
    fpResponse |= Wire.read() << 8;
    // mySerial.print("Received from frontPanel: 0x");
    // mySerial.println(fpResponse, HEX);

    int MuxPin_GND        = 0b0000000000000000;
    int MuxPin_ABSelect   = 0b0000000000000010;
    int MuxPin_ParSelect  = 0b0000000000000100;
    int MuxPin_SerSelect  = 0b0000000000001000;
    int MuxPin_IndSelect  = 0b0000000001000000;
    int MuxPin_LArrow     = 0b0000000010000000;
    int MuxPin_RArrow     = 0b0000000100000000;
    int MuxPin_ENC_CLK    = 0b0000100000000000;
    int MuxPin_ENC_DT     = 0b0001000000000000;
    int MuxPin_ENC_SWITCH = 0b0010000000000000;
    int MuxPin_CHB_EN     = 0b0100000000000000;
    int MuxPin_CHA_EN     = 0b1000000000000000;

    const int buttonsToCheck[5] = {
        MuxPin_IndSelect,
        MuxPin_ParSelect,
        MuxPin_SerSelect,
        MuxPin_CHA_EN,
        MuxPin_CHB_EN
    };

    // Flip the state according to the pressed buttons
    uint16_t newButtonState = fpResponse;
    if (newButtonState != buttonState) {
        mySerial.print("New button state: ");
        mySerial.println(newButtonState, HEX);
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

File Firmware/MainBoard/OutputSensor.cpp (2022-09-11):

#include "OutputSensor.h"

#include <Wire.h>

OutputSensor::OutputSensor(HardwareSerial &mySerial) :
    adc(MCP3428_ADRESS),
    mySerial(mySerial)
{ }

void OutputSensor::begin()
{
    // Reset devices
    MCP342x::generalCallReset();
    delay(1); // MC342x needs 300us to settle, wait 1ms
    // Check device present
    Wire.requestFrom(MCP3428_ADRESS, (uint8_t)1);
    if (!Wire.available()) {
        mySerial.print("No device found at address 0x");
        mySerial.println(MCP3428_ADRESS, HEX);
    } else {
        mySerial.print("Found MCP3428 at address 0x");
        mySerial.println(MCP3428_ADRESS, HEX);
    }
}

long OutputSensor::sampleChannel(MCP342x::Channel ch)
{
    long value = 0;
    MCP342x::Config status;
    // Initiate a conversion; convertAndRead() will wait until it can be read
    uint8_t err = adc.convertAndRead(
        ch, MCP342x::oneShot,
        MCP342x::resolution16, MCP342x::gain1,
        1000000, value, status
    );
    if (err) {
        mySerial.print("Error ");
        mySerial.print(err);
        mySerial.println(" sampling MCP3428");
    // } else {
    //     mySerial.print("Sampled value: ");
    //     mySerial.println(value);
    }
    return value;
}


void OutputSensor::sample()
{
    chAVoltage1000x = sampleChannel(MCP342x::channel1);
    chACurrent1000x = sampleChannel(MCP342x::channel2);
    chBVoltage1000x = sampleChannel(MCP342x::channel3);
    chBCurrent1000x = sampleChannel(MCP342x::channel4);
}

int OutputSensor::readOutput(Output sel)
{
    switch (sel) {
    case Output::VoltageA:
        return chAVoltage1000x;
    case Output::CurrentA:
        return chACurrent1000x;
    case Output::VoltageB:
        return chBVoltage1000x;
    case Output::CurrentB:
        return chBCurrent1000x;
    }
}

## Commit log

2022-09-11 Initial import of code
    First pieces of the main board firmware added.
2022-09-11 Initial import of Kicad files
    Import the main board KiCad files
    [45216-6X02.stp, EC11_Rotary_Encoder_Switched.step, MainBoard.kicad_pcb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]
2022-09-11 Import front panel design files
    [FrontPanel.kicad_pcb, FrontPanel.kicad_sch]
2022-09-11 Add MCP3428 ADC reads
    Initial code to read the output of the ADC to sample output
    voltage and current from channel A and B.
2022-09-16 Fix minor issues in PCB
    Fixed decoupling capacitors connectivbity
    Added test points to several networks
    [MainBoard.kicad_pcb, MainBoard.kicad_sch]
2022-09-16 Minor name change from adc to outSense
2022-09-16 Change 33V input resistor value
    The previous 5k1 ohm value was completely wrong.
    [MainBoard.kicad_sch]
2022-09-19 Add SWD connector
    USART programming is fraught with problems. It's much much
    better to use SWD through an STDC14 connector.
    Increased version number to v1.3
    [FrontPanel.kicad_pcb, FrontPanel.kicad_sch]
2022-09-25 Added Front Panel FW
    Add an initial version of the front panel firmware, with very ----------
    basic functionality.
    Also a class to control the outputs of the main board.
2022-09-25 Give names to all networks a name
    Add network labels to networks that didn't yet have a name.
    [FrontPanel.kicad_pcb, FrontPanel.kicad_sch]
2022-09-26 Import power input board files
    [PowerInput.kicad_pcb, PowerInput.kicad_sch]
2022-09-26 Add front panel FW tester
    Read button state and change the LED state according to button presses
2022-09-26 Fixed button state updates
    Button read requests are served by interrupts, so updates to the button
    state variable need to be atomic.
2022-09-29 Fix 2N7002 footprint
    The footprint for the 2N7002 MOSFETs was taken from the one
    of a 2N7000, which has the gate and the source pins exchanged.
    [FrontPanel.kicad_pcb, FrontPanel.kicad_sch]
2022-10-23 Fixes for the front panel
    Add a 3V3 regulator to convert the 5V input.
    Fix RX/TX mix-up
    Fix footprint for one last 2N7002 mosfet
    [FrontPanel.kicad_pcb, FrontPanel.kicad_sch]
2022-11-06 Initial code for the LCD UI
    Prototype stage.
    * Read the button state and change what is displayed on the LCD.
    * Display values for the outputs (mock values)
    * Display set values for the outputs (mock values, can't set them yet)
    * Change the output mode from independent to parallel to series
2022-11-06 Adapt BoardControl to use FrontPanel
    Instead of reading commands from the UART read the state of the
    buttons from the front panel using I2C to query the FP firmware.

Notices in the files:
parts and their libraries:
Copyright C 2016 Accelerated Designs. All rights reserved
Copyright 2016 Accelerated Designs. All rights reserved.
